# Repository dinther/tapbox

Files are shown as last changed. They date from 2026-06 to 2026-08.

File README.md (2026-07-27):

# tapbox

TapBox turns any music source into a steady Ableton Link tempo and downbeat master—whether the beat comes from a CDJ, an audio signal, or your own finger.

The device is based on a ESP32 controller that joins an [Ableton Link](https://www.ableton.com/en/link/) session over Ethernet or WiFi. Built on the [WT32-ETH01](http://www.wireless-tag.com/portfolio/wt32-eth01/) module with a MAX7219 8-digit 7-segment display. The famous silent sanwa button OBSF 30 serves as your tap button.



## Features

- **Four sources** — **Tap** (manual tap tempo), **Mic** (microphone auto-detects BPM, you tap the downbeat), **Line** (same detection from a 3.5 mm line-level input), and **CDJ** (Pioneer Pro DJ Link). Chosen with the Src menu item; the active source is shown by a bar on the display (top = CDJ, middle = Tap, bottom = Mic, top + bottom = Line)
- **Tap tempo** — tap 4 times to lock in BPM and phase-align to the Link session (Tap source)
- **Audio beat detection** — an INMP441 I2S microphone listens to the room and refines the tempo automatically via an FFT/mel-filterbank onset detector and a dynamic-programming beat tracker (`BTrack`), within a tunable BPM range of your tap — your tap is always ground truth; the detector can never wander off on its own. → [How beat detection works](BEAT_DETECTION.md)
- **Line-in beat detection** — a PCM1808 24-bit stereo ADC feeds a 3.5 mm line-level signal (mixer booth/aux out, media player, phone) into the same detector — no room noise, no mic-to-speaker acoustic delay
- **Pioneer CDJ sync** — passively listens for Pro DJ Link beat packets on the same network; bridges CDJ tempo directly into the Ableton Link session
- **Ableton Link** — joins the Link network automatically on boot; peers shown on display
- **Two-button control** — tap button for tempo and menu navigation; select button for confirm/back
- **Ethernet or WiFi** — Connects to your network as a client; browser config page for credentials; auto-failover to WiFi if no Ethernet present. Can also run as a **WiFi access point** or with a **direct Ethernet cable** to a laptop — no router needed.
- **Static or DHCP** — configure IP address, subnet, and gateway via the web config page
- **IP ticker on boot** — non-blocking scroll of connection type, IP address, and security PIN at startup (Eth, StA, or AP); the PIN doubles as the WiFi AP password and the web config page login; device is fully operational during the scroll
- **OSC control** — UDP server on port 8000 for remote tap, BPM set, nudge, and downbeat reset
- **Menu system** — on-device configuration with NVS persistence across power cycles
- **OTA updates** — open the menu, hold both buttons 3 s, release and confirm; tapbox checks for a newer version first and shows it for you to accept before it reboots to install — so it never burns a reboot when you're already up to date or can't reach the server
- **Factory reset** — open the menu, hold both buttons 8 s, confirm with select; returns device to store-bought state

<p align="center"><a href="https://beatline.xyz/projects/tapbox/" >Button</a></p>

## Hardware

| Component | Part |
|---|---|
| MCU / Ethernet | WT32-ETH01 (ESP32 + LAN8720A) |
| Display | MAX7219 8-digit 7-segment module |
| Input | Two momentary push buttons (tap + select) |
| Microphone | INMP441 I2S MEMS microphone (for Mic source) |
| Line-in ADC | PCM1808 24-bit I2S stereo ADC breakout + 3.5 mm TRS socket (for Line source) |
| Power / charging | Integrated lithium charge/discharge/boost module (often sold as "TP4056 boost module") — USB-C, 1 A three-stage charging, 5 V boost output, automatic charge/discharge switching, charge/discharge/polarity protection, 35 µA quiescent current |

### Pin Assignments

| GPIO | Function |
|---|---|
| IO35 | Tap button — input-only, needs **external 10 kΩ pull-up to 3.3 V** |
| IO39 | Select button — input-only, needs **external 10 kΩ pull-up to 3.3 V** |
| IO4  | INMP441 SCK (I2S bit clock) |
| IO12 | INMP441 WS (I2S word select) |
| IO36 | INMP441 SD (I2S data in) |
| IO14 | MAX7219 CLK |
| IO2  | MAX7219 DIN |
| IO15 | MAX7219 LOAD/CS |
| IO5  | PCM1808 SCKI — 8 MHz system clock, LEDC-generated (silk `RXD`) |
| IO17 | PCM1808 BCK — I2S bit clock, PCM1808-generated (silk `TXD`) |
| IO32 | PCM1808 LRC — I2S word clock, PCM1808-generated (silk `CFG`) |
| IO33 | PCM1808 OUT — I2S data in (silk `485_EN`) |

INMP441 wiring: **VDD → 3.3 V**, **GND → GND**, **L/R → GND** (selects the left channel), plus SCK/WS/SD as above.

PCM1808 wiring: **+5 V and 3.3 V** supplies (this breakout has no onboard regulator), **MD0 → 3.3 V**, **MD1 → 3.3 V** (Master mode, 256fs → 31.25 kHz sampling), **FMT → GND** (I²S format; silk-labelled `PMT` on some boards), **SCK ← IO5**, plus BCK/LRC/OUT as above. The PCM1808 masters the I2S bus; the ESP32 receives as a slave. 3.5 mm socket: **tip → LIN**, **ring → RIN**, **sleeve → the analog GND pin between LIN and RIN**.

> GPIO 0, 16, 18, 19, 21, 22, 23, 25, 26, 27 are used by the onboard Ethernet — do not reassign.  
> GPIO 34–39 are input-only with **no internal pull-up** — the tap/select buttons on IO35/IO39 therefore require external pull-ups.  
> IO12 is a flash-voltage strapping pin (used here for I2S WS); acceptable on the WT32-ETH01.

## Display Layout

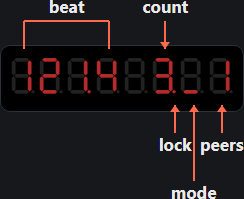
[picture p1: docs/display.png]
Display layout


- **beat** — current BPM, four digits with decimal point (`120.0`)
- **source bar** — horizontal segments: **top = CDJ**, **middle = Tap**, **bottom = Mic**, **top + bottom = Line**
- **count** — beat position in the bar (1–4, or up to your time signature)
- **lock dot** — decimal point on the count digit: **solid** = locked (CDJ active / audio stable / tap set); **blinking** = Mic or Line source searching; **off** = no lock
- **peers** — number of other Ableton Link peers on the network

**Menu mode:**
```
[ label 0 ][ label 1 ][ label 2 ][ label 3 ][ blank ][ value right-justified ]
```
Menu mode example: Beat label with value 4

Value flashes at 4 Hz in edit mode.

## Controls

| Action | Result |
|---|---|
| Tap button (normal mode) | Tap tempo |
| Tap button (menu nav) | Advance to next item |
| Tap button held (menu edit) | Auto-increment value (5/sec after 500 ms, 20/sec after 1500 ms) |
| Select button short press | Enter menu / confirm |
| Select button long press (1 s) | Back / exit menu |

## Menu

| Label | Setting | Values |
|---|---|---|
| Beat | Time signature | 2, 3, 4, 5, 6, 7 |
| Led | Display brightness | 1 – 4 (live preview) |
| Src | Source | Cdj · Aud (mic) · `LinE` (line-in) · tAP (tap) |
| Lan. | Network mode | Auto (DHCP) · Stat (static) · AP (WiFi access point) |
| Addr | Current IP address | read-only; shows last octet; press **select** to scroll full IP across display |
| vEr | Firmware version | read-only; shows major.minor.patch |
| done | Exit menu | returns to normal mode |

Src selects the source. The tuning parameters for the audio beat detector (shared by the Mic and Line sources), plus the static IP address, subnet mask, and gateway, are **web-only** (Network and BPM tuning tabs on the web config page, not on-device menu items) — see [BEAT_DETECTION.md](BEAT_DETECTION.md).  
Changing the network mode reboots after a 2-second `bOOt` display.  
Addr is read-only. Navigating to it shows the last octet of the current IP as a quick reference; pressing **select** scrolls the full IP address across the display.  
Menu times out after 6 seconds of inactivity without saving. The menu resumes at the last-visited item when re-opened.

> Factory reset and OTA update are **not** in the menu — see [System Functions](#system-functions) below.

## System Functions

Both system functions are triggered from **within the menu** by holding both buttons simultaneously. Open the menu first (select short press), then hold both buttons.

### OTA Firmware Update

Open the menu, then hold both buttons for **3 seconds**. The display shows UPd.----. Release — the display shows UPd Yes. Press **select** to check for an update. tapbox contacts the server and compares versions — **no reboot yet**:

- **Already up to date** → shows `UPd no` and returns to the menu.
- **Can't reach the server** (no internet route) → shows `UPd Er` and returns to the menu.
- **A newer version is available** → shows `UP` followed by that version number (e.g. `UP 1.15.0`) and waits for your decision. Press **select** to install it, or **tap** (or wait) to cancel.

Only when you accept the shown version does tapbox save the update flag, erase OTA data if needed, and reboot. On the next boot, as soon as it gets a network connection, it downloads and installs that firmware — the display shows `UPd.` with a progress percentage, then done before rebooting into it.

### Factory Reset

Open the menu, then hold both buttons for **8 seconds**. The display shows UPd.---- at 3 s then rSet Yes at 8 s. Release and press **select** to confirm. tapbox resets all settings and reboots. Press **tap**, hold **select**, or wait 6 seconds to cancel.

## WiFi

tapbox prefers Ethernet. WiFi is used automatically when no Ethernet cable is present, and as a fallback if the cable is unplugged while running.

**First-time setup:**

1. Boot tapbox without an Ethernet cable.
2. Connect your phone or laptop to the **tapbox** WiFi network.
3. Use the 8 digit password shown on the device on bootup. (It is the number shown after the IP address)
4. Open **http://192.168.4.1** in a browser.
5. Enter your regular WiFi SSID and password and tap **Save Network — tapbox will reboot**.
6. tapbox reboots and connects to your network as a client.
7. You know it worked when you see "sta" followed by an IP address on bootup.

The ESP32 radio supports **2.4 GHz only**. If your router broadcasts separate 2.4 GHz and 5 GHz SSIDs, use the 2.4 GHz one.

If WiFi credentials are stored but the connection fails, tapbox falls back to AP mode automatically so you can reconfigure without a factory reset.

## Direct Connection — No Network Required

tapbox can sync with a PC running Ableton Live (or any Link-enabled app) — or directly with a Link-enabled standalone player — without a router or existing network. Three approaches work: tapbox's own WiFi access point, a direct Ethernet cable with automatic addressing, or a direct cable with static IPs on both devices.

### WiFi AP mode

The simplest option — tapbox creates its own WiFi network and everything runs on it.

1. In the menu, navigate to Lan. and set it to AP. Confirm with select — tapbox reboots.
2. On your laptop, connect to the **tapbox** WiFi network and enter the 8 digit password shown on the device at bootup.
3. Ableton Link is active immediately. Tap to set tempo and phase.
4. In AP mode, the web config page is at **http://192.168.4.1** for display and network settings.
5. OSC commands reach tapbox at **192.168.4.1 port 8000**.

> OTA firmware updates are not available in AP mode as there is no internet path. CDJ sync is also unavailable — Pioneer players use a wired network and do not join a WiFi access point.

### Direct Ethernet — automatic

A single patch cable between tapbox and a computer (or a Link-enabled player such as a Denon SC6000) needs **no configuration at all**. Leave tapbox on its default Lan. = `Auto` setting and connect the cable:

1. tapbox looks for a DHCP server for a few seconds; with none on the wire it self-assigns a **link-local address** (`169.254.x.x`) and scrolls it on the display. The address looks random but is derived from the device's MAC, so it stays the same every time.
2. The other end does the same — Windows ("APIPA"), macOS, Linux, and Engine OS players all self-assign in the same `169.254.0.0/16` range when DHCP is absent. On Windows the adapter shows **"Unidentified network — No internet"**; that's normal for a bare cable.
3. Both ends now share a subnet: Ableton Link discovers the peer, the web config page answers at the address on the display, and OSC works on port 8000.

Give the computer up to a minute to give up on DHCP and self-assign — `ipconfig` showing an *Autoconfiguration IPv4 Address* means it's ready.

> **One self-assigned adapter at a time.** Link-local addresses don't identify *which* cable they live on, so if a computer has **several** network adapters in the self-assigned state at once (e.g. two direct cables to different devices), the OS can route the range out of only one of them and the others become unreachable. One direct cable per machine works flawlessly; for anything more elaborate — or any show rig where addresses must never change — use the static IP plan below.

> OTA firmware updates are not available on a direct cable (no internet path).

### Direct Ethernet — static IPs

The managed alternative: both ends set to a fixed address. Addresses never change between sessions, which suits saved OSC configurations and multi-device rigs.

Modern hardware (including the WT32-ETH01 and USB-to-Ethernet adapters) supports auto-MDIX, so a standard patch cable works — no crossover cable is required.

**tapbox — set a static IP:**

1. In the menu, set Lan. to Stat.
2. On the web config page's Network tab, set the static IP, subnet, and gateway. Use a private range that is not in use on any other interface — for example:

   | Setting | Example |
   |---------|---------|
   | `IP  ` | `192.168.10.1` |
   | `Sub.` | `255.255.255.0` |
   | `Hub.` | `192.168.10.1` |

3. Connect the cable. tapbox boots straight to its static address with no DHCP wait.

**Laptop — set the Ethernet adapter to a static IP on the same subnet:**

| Setting | Example |
|---|---|
| IP address | `192.168.10.2` |
| Subnet mask | `255.255.255.0` |
| Default gateway | `192.168.10.1` *(or blank)* |

The web config page is at your chosen **http://192.168.10.1**. Ableton Link and OSC work on the same address. The laptop's WiFi can remain connected to the internet independently.

> Do not set the laptop gateway to an address outside the tapbox subnet — it will cause routing errors on that interface. Leaving the gateway blank or pointing it at the tapbox IP is safe.

### Windows Firewall — letting Link through

Ableton Link needs to *receive* UDP packets, and the Windows Firewall blocks unknown inbound traffic. The telltale symptom: you can ping tapbox and open its web page, but your tapbox display shows **0 peers** — or sees tapbox while tapbox's peers count stays at 0.

Two things make this common:

- Windows classifies a direct cable as an **"Unidentified network"** and applies the strict **Public** firewall profile, even if the app was already allowed on Private networks.
- If the "allow access" prompt on an app's first run was ever cancelled, Windows silently created a **Block** rule that keeps winning on every network.

**To allow your Link app (Ableton Live, MadMapper, …):**

1. Press **Start**, type "firewall", open **Allow an app through Windows Firewall**.
2. Click **Change settings** (needs administrator rights).
3. Find your app in the list. Tick the checkbox on the **left of its name**, then tick both the **Private** and **Public** columns.
4. Click **OK** and restart the app.

Or as a single command in an **administrator** PowerShell (replace the name with the app's entry as it appears in the firewall list):

```powershell
Set-NetFirewallRule -DisplayName "Ableton Live 12 Trial" -Action Allow -Profile Private, Public
```

If the app is not in the list yet, launch it once, enable Link, and accept the firewall prompt — ticking **both** network types.

## Web Configuration

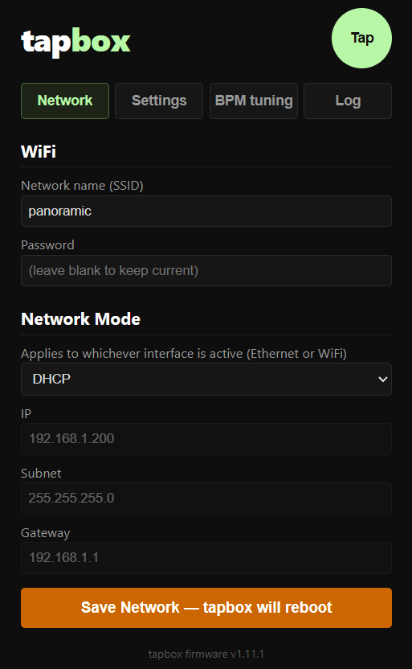
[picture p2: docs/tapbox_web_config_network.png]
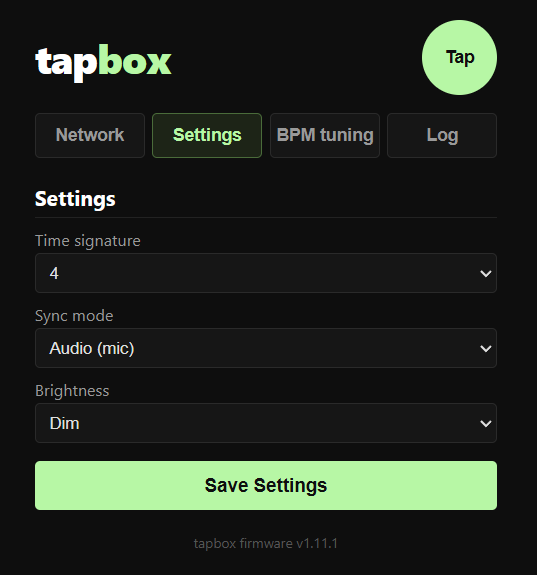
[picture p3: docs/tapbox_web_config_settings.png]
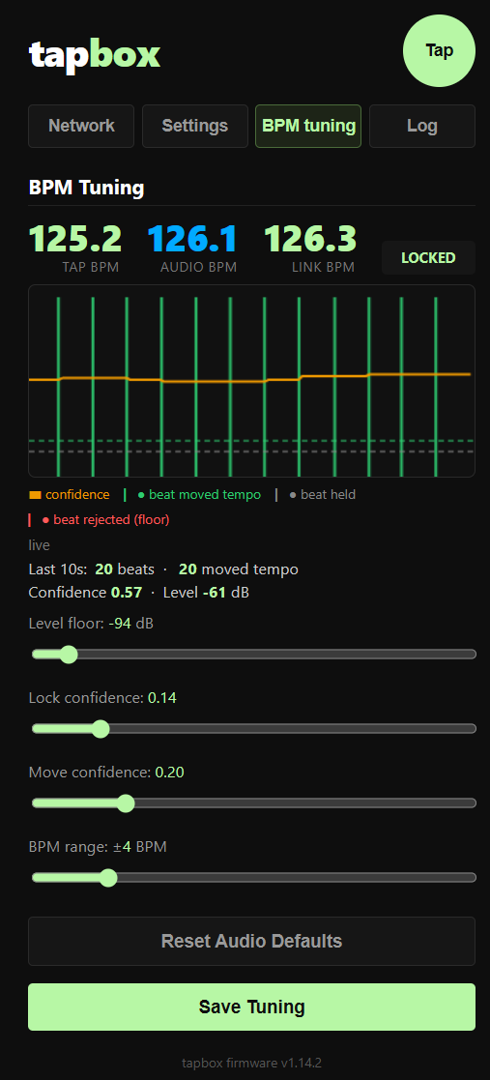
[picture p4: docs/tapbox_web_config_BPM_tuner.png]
  

The config page at `http://<tapbox-ip>` is accessible from any browser over Ethernet or WiFi. A **Tap** button above the tabs works from any of them — same tap the physical button drives. It has four tabs:

| Tab | Fields | Button | Effect |
|-----|---|---|---|
| Network | WiFi SSID/password, Ethernet mode, static IP/subnet/gateway | Save Network — tapbox will reboot | Saves and reboots |
| Settings | Time signature, source, brightness | Save Settings | Saves and applies live — no reboot |
| BPM tuning | Level floor, lock confidence, move confidence, BPM range, plus a live confidence chart | Save Tuning | Applies live as you drag; see [BEAT_DETECTION.md](BEAT_DETECTION.md) |
| Log | Live scrolling log of tap/arm/lock events over the same WebSocket the chart uses — no controls, view-only | — | — |

## OSC Interface

Send UDP packets to the device on **port 8000**.

| Address | Argument | Action |  
|---|---|---|
| `/tap` | — | Same as the tap button |
| `/bpm` | `float` or `int` | Set BPM directly |
| `/signature` | `int` | Set time signature (2–7) |
| `/nudge` | `int` (ms, signed, optional) | Nudge phase by `ms` (+ = advance, − = retard); no argument = 20 ms |
| `/downbeat` | — | Reset downbeat to now |

## Installing

Flash tapbox to your WT32-ETH01 directly from your browser — no software installation required:

**[Open Web Installer](https://dinther.github.io/tapbox/)**

Requires Chrome or Edge. Windows users may need the [CH340 driver](https://www.wch-ic.com/downloads/CH341SER_EXE.html) if the board is not detected.

Pre-built binaries are also available on the [Releases](https://github.com/dinther/tapbox/releases) page for manual flashing with esptool.

## Tools

Two Python scripts in `tools/` assist with development and testing. Both require Python 3 and no external packages.

### CDJ Simulator (`tools/cdj_sim_web.py`)

Broadcasts genuine Pro DJ Link 0x28 beat packets on UDP port 50001 — useful for testing CDJ sync without real hardware.

```bash
python tools/cdj_sim_web.py [bpm] [player]
```
{47560FA2-C87A-4E2B-8EA1-346BB672038C}

Opens a browser-based control page at **http://localhost:8080** with:
- Live BPM display with ±1 / ±0.1 nudge buttons and a slider
- Beat-in-bar indicator (4 circles, beat 1 highlighted in amber)
- Player selector (1–4)
- Stop / Start toggle (tests the 2-second CDJ timeout on tapbox)
- **Downbeat** button — sends `Bb=1` immediately, triggering a bar-phase snap on tapbox

### Link Monitor (`tools/link_monitor.py`)

Prints the current Ableton Link session tempo and peer count to the terminal, useful for verifying that tapbox is pushing the right BPM into the Link session.

```bash
python tools/link_monitor.py
```

## Building

Requires [PlatformIO](https://platformio.org/).

```bash
# Build
python -m platformio run

# Build and flash
python -m platformio run --target upload
```

## License

MIT

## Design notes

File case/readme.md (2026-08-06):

## CAD Files
The case was created with OpenSCAD. This is the included tapbox_case.scad file. This is a open source parametric script driven cad program which is perfect for the creation of 3D printable parts. You can find OpenSCAD here: https://openscad.org/

The bottom four lines of the source can be uncommented for the part you want to generate.

## STL Files
You can also just use the STL files included in this folder. These are optimized for the specific parts I have on hand but they may suit you too.

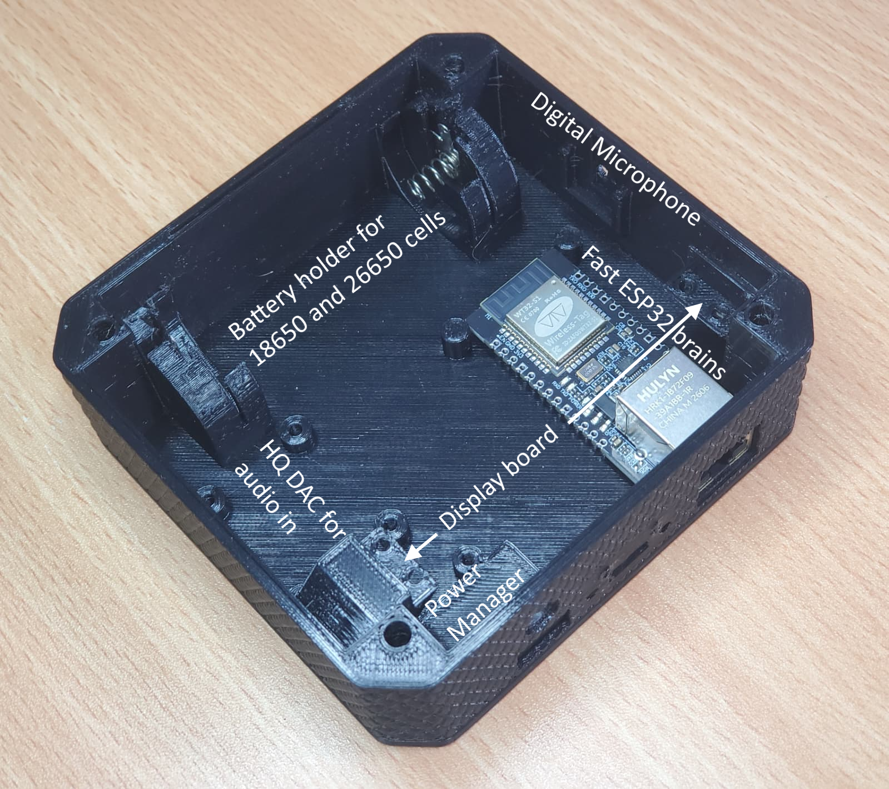
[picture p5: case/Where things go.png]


## Texturizing
I textured part of the case in order to hide layer lines that are otherwise unavoidable with FDM printing. For this I used https://bumpmesh.com an excellent browser based stl texturizer. I uploaded texture.png for the texture in this program.

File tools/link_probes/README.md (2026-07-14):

# Ableton Link probe scripts

Packet-level diagnostics for Link discovery/session problems, written while
debugging why Link peers fail to sync over a direct Ethernet cable with
link-local (169.254.x.x) addressing. Python 3 standard library only.

All scripts have the local interface addresses and the peer's address
**hardcoded near the top** (`ETH_IP`, `WIFI_IP`, `TAPBOX`) — adjust them to
your setup before running (`ipconfig` shows yours; the tapbox display scrolls
its own).

| Script | What it shows |
|---|---|
| `link_sniff_nodes.py` | Which Link peers (by node id) are transmitting on which interface. Confirms TX and interface binding without trusting any app's UI. |
| `link_pkt_compare.py` | Full decode of one ALIVE per peer: protocol version, group id, node id, tempo, session id, measurement endpoint. Spots structural incompatibilities. |
| `link_mcast_probe.py` | Replays a captured ALIVE to a device via unicast and via multicast and watches for a RESPONSE — separates message-processing failures from multicast-delivery failures. |
| `link_fake_peer.py` | Impersonates a complete Link peer (fresh node/session id, measurement endpoint pointed at its own socket) and reports whether the device under test answers discovery and initiates measurement pings. The full merge handshake, observable end to end. |
| `laseros_pong_test.py` | The decisive subnet-filter test: captures a genuine measurement ping, replays the identical bytes from a *same-/24* source, and watches for a pong. A responder that pongs the replay but ignored the original is filtering by source subnet. |

## Background

Ableton Link builds from Feb 2024 (upstream commit `a273b36`) to Mar 2026
(removed in `d466f42`) contain a hardcoded /24 source-subnet filter in
discovery. Link-local addressing is a /16, so two directly-cabled devices
usually land in different /24s and a filter-era peer goes silently deaf to
the other end. tapbox firmware ≥ v1.14.2 carries the upstream removal; these
scripts identify the same defect in other Link applications.

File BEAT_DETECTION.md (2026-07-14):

# tapbox — Audio Beat Detection

How the audio BPM detection works, end to end.

This describes the two **audio sources** — **Mic** (`MODE_MIC`, INMP441
microphone) and **Line** (`MODE_LINE`, PCM1808 line-in ADC) — out of the four
sources (CDJ / Mic / Line / Tap). The two differ only in capture hardware and
sample rate (§3); from the FFT onward (§4–13) the pipeline is identical, so
where the prose below says "the mic," read "whichever audio source is active."
All of the logic lives in `mic_task()` and `do_tap()` in `src/main.cpp`, plus
the DSP core ported (MIT-licensed) from
[absent42/esphome-audio-reactive](https://github.com/absent42/esphome-audio-reactive)
into `src/dsp/`.

> Diagrams use [Mermaid](https://mermaid.js.org/) (GitHub renders them inline)
> plus ASCII where a waveform is clearer than a flowchart.

---

## 1. Design philosophy

The hard problem in automatic beat tracking is the **downbeat** — knowing which
pulse is "beat 1". tapbox sidesteps it by splitting the job between the human and
the machine:

| Job | Owner | Why |
|-----|---|-----|
| **Tempo** (BPM) | the **audio source** (mic or line-in) | machines are good at measuring intervals |
| **Downbeat** (phase / "beat 1") | the **tap button** | humans hear musical phrasing |

So: **you tap the downbeat, the detector carries the tempo.** Your tap is *ground
truth*; the detector is only ever allowed to refine and track *around* it. This single
rule is why the system stays trustworthy — the detector can never wander off on its own.

```mermaid
flowchart LR
    A[Music in the room] -->|acoustic| MIC[INMP441 mic]
    B[Mixer / player output] -->|3.5mm line| ADC[PCM1808 ADC]
    MIC -->|tempo| LINK[Ableton Link grid]
    ADC -->|tempo| LINK
    TAP[Your tap] -->|downbeat / anchor| LINK
    LINK --> OUT[Synced devices]
```

---

## 2. The detection pipeline

A proper FFT-based pipeline, ported from a MIT-licensed ESP32 audio-analysis
library and re-derived for tapbox's rates — 32kHz mic / 31.25kHz line-in (the
library targets ESPHome devices at 22.05/44.1kHz):

1. **`FFTProcessor`** — real FFT via [kissfft](https://github.com/mborgerding/kissfft) (vendored, BSD-3-Clause)
2. **`MelFilterbank`** — 32-band log-mel spectral representation
3. **`SuperFluxOnset`** — log-mel, max-filtered spectral flux (Böck & Widmer,
   DAFx 2013) — tuned to reject vibrato/legato and pick genuine attacks across
   the whole spectrum, not just one band
4. **`BTrack`** + **`TempoEstimator`** — a cumulative-score dynamic-programming
   beat tracker with fractional-lag harmonic-template tempo induction and a
   leaky-integrator smoother, re-implemented against the
   [adamstark/BTrack](https://github.com/adamstark/BTrack) reference

---

## 3. Capturing audio (I2S)

Two independent capture paths; `mic_task()` is the single reader and consumes
whichever one the Source setting selects, resetting the whole pipeline
(filterbank geometry, SuperFlux, BTrack, arm/lock state) on a switch — so
re-tap once after switching sources.

**Mic** (`MODE_MIC`, I2S0, ESP32 as master):

- **INMP441** digital I2S MEMS mic, `L/R` tied to GND.
- Sample rate: **32 kHz**.
- INMP441 channel selection on the ESP32 is a known finicky point (L/R→GND
  *should* select the left slot, but configs don't always behave). In our
  bring-up, **mono mode returned all-zero samples on both slot settings**, while
  reading **both** slots in stereo and using only the **left** samples worked
  reliably — so that's what we do (`i += 2` through the buffer). This is an
  empirical workaround for our setup, not a documented driver bug.

**Line** (`MODE_LINE`, I2S1, ESP32 as slave):

- **PCM1808** 24-bit stereo ADC fed from the 3.5 mm line input; both channels
  are averaged to mono into the same ring buffer.
- The **PCM1808 masters the I2S bus** (MD0/MD1 strapped high = Master mode,
  256fs): it derives BCK (2 MHz) and LRCK internally from an **8 MHz system
  clock** the ESP32 generates with LEDC (80 MHz APB ÷ 10, an exact integer
  division — a fractional divider would jitter, and SCKI jitter degrades the
  ADC). Single clock domain by construction; the ESP32 just listens as an
  I2S slave receiver.
- Sample rate: 8 MHz ÷ 256 = **31.25 kHz** — deliberately close to the mic's
  32 kHz so the pipeline keeps its character across sources.
- See `PCM1808_PLAN.md` for the full bring-up (wiring, straps, scope
  checkpoints).

---

## 4. FFT + spectral analysis

Raw samples accumulate into a ring buffer; once **1024 samples** (a 32ms window)
are available, a real FFT runs and the window slides forward by a **512-sample
hop** (16ms) — 50% overlap, giving a **62.5Hz** frame rate for everything
downstream (`kFrameHz` throughout `src/dsp/`).

On **line-in** the same 512-sample hop at 31.25 kHz gives **61.035 Hz** — but
`kFrameHz` is a compile-time constant inside `btrack.h`/`tempo_estimator.h`,
so the estimator's reported BPM would read 2.4% high on line-in. `mic_task()`
corrects this at the point of consumption: line-in BPM readings are scaled by
61.035/62.5 (×0.97656) before the octave fold, gates, and Link ever see them.
Confidence is unitless and needs no scaling.

```mermaid
flowchart LR
    I2S["I2S read: ~128 samples/read"] --> RING["RingBuffer&lt;float,2048&gt;"]
    RING -->|"1024 samples available"| FFT["FFTProcessor&lt;1024&gt;<br/>(kissfft, Hamming window)"]
    FFT -->|"magnitudes²"| MEL["MelFilterbank&lt;32,1024&gt;<br/>80Hz–16kHz, log-mel"]
```

512 usable FFT bins (`1024/2`) at 32kHz give 31.25Hz/bin resolution — coarser
than the upstream library's own 2048-pt/44.1kHz config (21.5Hz/bin), but half the
per-FFT compute cost, which matters since this all runs inline in `mic_task`
alongside I2S reads, sharing the chip with WiFi/Ethernet/HTTP/Link (no core
pinning is used anywhere in this codebase).

**This is the fast path** — the FFT→Mel→SuperFlux→BTrack chain (§3–6) runs on
*every hop* (62.5Hz). `BTrack::process()` is a stateful per-frame machine with
internal countdown timers; it must be fed every hop to behave correctly.

---

## 5. Mel filterbank + SuperFlux onset detection

The squared FFT magnitudes feed a 32-band triangular mel filterbank (80Hz–16kHz
on the mic; the top band drops to 15kHz on line-in, under its 15.625kHz Nyquist)
— the same perceptually-scaled representation used in most music-information-
retrieval onset detectors, giving finer resolution at low frequencies (where
kicks and bass live) than a linear FFT bin split would.

`SuperFluxOnset` (Böck & Widmer, DAFx 2013) then computes onset **strength** per
frame:

1. Log-compress the current mel frame
2. **Max-filter** the previous frame across ±3 neighboring mel bins — this
   specifically suppresses vibrato/legato content, which would otherwise look
   like a continuous stream of small "onsets" to a naive frame-difference
   detector
3. Half-wave-rectified difference between the current (log) frame and the
   max-filtered previous one = flux
4. Adaptive peak-picking (local-max window ± 3 frames, must exceed the local
   mean by a delta threshold over a ±10/+3 frame window) with a minimum
   36–48ms between onsets

The result is a continuous **onset-strength** signal plus a boolean **event**
flag on frames where a genuine onset is confirmed — this strength signal is what
feeds tempo tracking (§6), every hop, regardless of whether `event` fired.

---

## 6. BTrack — tempo tracking

`BTrack` consumes the onset-strength signal every hop and maintains:

- An **onset-history ring** (`kHistoryLen` = 384 frames ≈ 6.1s at 62.5Hz)
- A **cumulative-score** dynamic-programming array, blending the current onset
  strength with the best-scoring past state within a `[beat_period/2,
  2×beat_period]` window (log-Gaussian weighted) — this is what lets it predict
  *when* the next beat should fall, not just detect that a beat happened
- A **beat-prediction** step that extrapolates the cumulative score forward and
  picks the most likely next beat frame

**Tempo induction** (working out the actual BPM, as opposed to predicting the
next beat *given* a known BPM) runs once per predicted beat and is delegated to
`TempoEstimator`:

- Scores a continuous **60–180 BPM grid** (121 candidates, 1-BPM steps) using a
  **fractional-lag harmonic template** (4 harmonics of the candidate's beat
  period, evaluated at exact fractional lags into the autocorrelation, avoiding
  the bias integer-lag binning would introduce)
- A gentle **log-normal prior** centered on 120 BPM nudges octave ambiguity
  without creating a hard attractor
- A **leaky integrator** smooths estimates across updates — old evidence decays
  geometrically, so a wrong lock is escapable within roughly 10 beats
- **Confidence** is the fraction of the smoothed state's mass sitting within
  ±2 BPM of the current best estimate — high on real rhythmic music, near-zero
  on noise or silence — gated by requiring 4 consecutive updates to agree within
  ±3 BPM before calling the estimate "locked"

`BTrack` publishes `{bpm, beat_phase, confidence, beat_event}` every hop.
Confidence is forced to 0 for the first ~3 seconds after reset (`kWarmupFrames`)
while the onset-history ring fills with real data.

**Known limitation** (documented in `tempo_estimator.h`, inherited from the
upstream library's own measurements): the reliable range is **~85–160 BPM**.
Outside it, octave/sub-harmonic aliasing dominates — material with strong
eighth-note content below ~85 BPM confidently reports double tempo; above ~164
BPM a 2:3 or 1:2 alias can win. This isn't a tapbox-specific bug; it's an
inherent property of autocorrelation-based tempo induction on eighth-note-heavy
material, present in the reference implementation this was built against.

---

## 7. Arming — the tap is ground truth

With a Mic or Line source, the detector is **display-only until you tap.** Your tap sets two
references used by everything downstream:

- `g_mic_tapAnchor` — the **anchor** tempo (centre of the octave fold and the BPM range gate, §8)
- `g_mic_tracked` — the **applied** tempo (what goes to Link)

All three — Tap, Audio, Link — are shown live as big numbers at the top of
the BPM tuning tab, so you can see your own tap alongside what the mic is
hearing and what's actually being published.

**Tap grammar** (the box infers intent from how many taps arrive < 2 s apart):

```mermaid
flowchart TD
    T[Tap] --> N{How many taps<br/>in this session?}
    N -->|1 tap, then stop| ONE[Accept current mic BPM<br/>+ set downbeat = now]
    N -->|4+ taps| FOUR[Override tempo to tapped BPM<br/>+ re-anchor the mic]
    ONE --> ARMED[Armed - mic now tracks around anchor]
    FOUR --> ARMED
```

- **One tap** = "I agree, beat 1 is *now*" — accepts the mic's current estimate
  and sets the downbeat.
- **Four taps** = override the tempo with your own tapping, re-anchoring the mic.
- Once armed and locked, a **lone tap just re-syncs the downbeat** without
  touching the tempo (the mic owns BPM).

---

## 8. Follow/hold — applying BTrack's tempo

A beat only reaches the tiers below if it clears an **absolute level floor**
first (`g_micFloor`, dB, BPM tuning tab slider, default off at -100dB).
`SuperFlux` measures *relative* spectral change, so a quiet room still
produces confident, periodic "beats" out of something as unmusical as
keyboard typing — there is no loudness floor anywhere upstream of this gate.
A beat whose level falls below `g_micFloor` counts for **nothing**: not lock,
not PLL, not tempo. (Discovered when typing near an armed, silent tapbox
produced a run of confident, evenly-spaced "beats.")

The level checked is **smoothed, not the raw per-hop reading**: a single
32ms FFT hop's power swings roughly 20dB on room noise alone (measured
2026-07-09 — mic self-noise/room hum, not transient events), which is too
noisy to gate on directly. `frameLevelDb` (raw) feeds `levelEmaDb`, an
~800ms EMA (0.98/0.02 blend at the 62.5Hz hop rate); the floor gate and the
web page's Level readout both read `levelEmaDb`, not the raw value.

Confidence is **two-tier**, both tiers tunable sliders (`g_micConfSil` /
`g_micConfMove` on the BPM tuning tab, defaults 0.30 / 0.60) because usable
confidence varies a lot with the mic and the room — there's no fixed value
that works everywhere. Above the **lock** tier a beat keeps the lock alive
and the PLL phase-nudging (§9): beat *timing* stays useful even when the
tempo estimate is smeared. But **moving** the tempo requires the **move**
tier — most of `BTrack`'s probability mass agreeing on one value. This
matters because a quiet, beat-free passage can keep confidence just above a
low, fixed floor while the estimate wanders onto a harmonic alias — requiring
higher confidence to move turns that passage into a HOLD instead of an
alias-driven jump.

**FOLLOW** — on each beat clearing the level floor and the move tier, the
tempo is driven directly:

**(a) Octave fold toward the tap anchor** — the one disambiguation `BTrack`
demonstrably still needs (§6's ~85–160 BPM aliasing limit). The *operator*
knows which octave they meant; the fold applies that knowledge:

```c
while (cand > anchor * 1.4) cand *= 0.5;
while (cand < anchor * 0.7) cand *= 2.0;
```

The fold anchors to the **fixed tap anchor**, not the wandering output —
anchoring to the output would let a drift feed back on itself.

**(b) Snap, with an anti-flicker deadband** — if the folded candidate differs
from the tracked tempo by more than 0.4 BPM, the tracked tempo is set **equal
to it** in one step. No crawl: Link converges as fast as `BTrack` does. Moves
of 0.4 BPM or less are ignored, so the tempo published to every Link peer
doesn't flicker with estimation jitter — and because every real move lands
exactly *on* the candidate (rather than a slew stopping short of it), there is
no standing measured-vs-Link offset for the phase-lock (§9) to absorb.

**(c) BPM range gate** — a candidate more than `g_micRange` BPM from the tap
anchor (`g_mic_tapAnchor`, default ±6, tunable 1–20 on the BPM tuning tab)
does not move the tempo, full stop, no matter how confident the beat is.
Unlike (a)/(b), this isn't a fixed constant — it's the main knob for how much
you trust audio sensing to refine around your tap versus treating the tap as
the whole story (2026-07-09 redesign: the anchor itself never moves except by
re-tap; this gate only bounds how far `g_mic_tracked` may wander from it).
Binary in/out for now, no graduated confidence-vs-distance requirement yet.
Because `g_mic_tracked` can only ever be *set* to a candidate that already
passed this check, it's bounded to anchor±range by construction — there's no
separate clamp step the way the old fixed ±20% rail needed.

**HOLD** — anything below the move tier (silence, a breakdown, a beat-free
passage, a confidence dip mid-transition), below the level floor (typing,
handling noise), or **outside the BPM range gate** (a candidate too far from
the anchor to trust) freezes the tempo at its last good value. Nothing
chases low-confidence, too-quiet, or out-of-range readings; beats clearing
the floor and the lock tier (but not move-tier confidence, or not in range)
still maintain the lock and phase alignment, and `tapbox`'s lock drops after
the timeout (§9) if even those stop — but the tempo number stays put until a
beat clears every tier at once.

Beat events are latched across the fast 62.5Hz hop loop (`btBeatSincePoll` in
`mic_task()`) — each latch also stamps the beat hop's own smoothed level and
timestamp (`beatLevelDb`/`beatMs`, see the level-floor note above), so the
gate judges the beat's actual energy rather than whatever the slower 20Hz
poll sees — and consumed by that poll, so no `beat_event` is ever missed
between polls.

---

## 9. Applying to Link — tempo *and* phase-lock

```c
abl_link_set_tempo(session, tracked, t);          // always: tempo
if (locked) {                                      // only once locked:
    beat    = abl_link_beat_at_time(session, t);
    nearest = round(beat);
    fixed   = beat + 0.15 * (nearest - beat);      // low-gain phase nudge
    abl_link_force_beat_at_time(session, fixed, t);
}
```

Once **locked** (4 consecutive confident beats), a low-gain **phase-locked loop**
gently pulls the beat grid so each detected beat sits on the **nearest** beat —
never a whole bar, so the bar position you tapped is preserved.

---

## 10. Lock state & lifecycle

```mermaid
stateDiagram-v2
    [*] --> DisplayOnly: enter Mic or Line source
    DisplayOnly --> Armed: tap (sets anchor + downbeat)
    Armed --> Locked: 4 consecutive confident beats
    Locked --> Armed: no confident beat for 6 beat-periods (min 3.5s)
    Armed --> DisplayOnly: leave Mic/Line source
    Locked --> DisplayOnly: leave Mic/Line source
    Locked --> Locked: re-tap = re-sync downbeat
```

There are two layers of gating, worth keeping distinct:

- **`BTrack`'s own confidence/lock** (§6) — internal to the DSP, decides whether
  its BPM candidate is trustworthy at all. Can flicker during an active tempo
  change (e.g. a DJ pitch-bending a track) — that's expected, not a bug.
- **tapbox's armed/locked state** (this section) — fed by *confident* beats
  (§8's FOLLOW events): requires 4 confident beats in a row, drops after 6
  beat-periods (minimum 3.5s) without one.

A sustained confidence dip in `BTrack` (silence, a breakdown) puts the tempo
in HOLD and, past the timeout, drops tapbox's lock — but `BTrack`'s own `bpm`
field keeps updating underneath regardless of confidence, so it typically
re-locks within a couple of beats once confident beats return.

---

## 11. Tuning chart — BTrack's own signals, live

The web config page's **BPM tuning** tab chart plots exactly the quantities
the follow/hold logic (§8) compares, in their native units, over a rolling
6-second window.

**2026-07-09: the chart was a BPM strip (raw/Link BPM traces, top) stacked
over a confidence strip (bottom) — the BPM strip was removed entirely** (it
plotted a hardcoded ±20% band that no longer matched the real gate once
`g_micRange` replaced the fixed clamp, and the numbers it showed are already
covered live by the Tap/Audio/Link readouts at the top of the tab, §7). What
remains is a single **confidence strip**: the confidence trace (orange)
against the **lock** (grey dashed) and **move** (green dashed) slider
thresholds, redrawn live as the sliders move, plus a vertical tick per
BTrack-predicted beat — bright green if it cleared the move tier and the BPM
range gate (it drove the tempo), dim grey if it only cleared the lock tier
(including a beat confident enough to move tempo but outside the BPM
range), **red if BTrack predicted a beat but the level floor rejected it**.
A run of grey/green ticks poking above the move line with no music playing
is the typing-noise failure mode; a run of RED ticks during real music is
the opposite failure — real beats being wrongly rejected.

The chart, the live **Confidence**/**Level (dB)** readout beneath it (Level
is the same ~800ms-smoothed value the floor gate checks, §8), and the
"Last 10s: N beats · M moved tempo" line are all fed by the same 20Hz
telemetry packet `mic_task()` pushes over the `/ws` WebSocket. The chart
lives in the embedded copy in `http_get_root()` (`mDraw()`).

---

## 12. Live event log (web page "Log" tab)

A fourth tab on the web config page shows a scrolling, timestamped log of
notable events — useful for testing without a serial cable attached (e.g.
watching tempo tracking behavior while changing pitch/speed in DJ software).
Logged over the same `/ws` WebSocket connection the tuning chart uses,
distinguished from the telemetry CSV by an `L` prefix.

**Logged today:**
- Tap events — armed, downbeat re-synced, tap override (from `do_tap()`)
- Lock transitions — "Locked at N BPM" / "Lock lost (was N BPM)" (edge-triggered
  in `mic_task()`)

**Not logged:** a per-beat trace of `BTrack`'s raw (pre-confidence-gate) BPM
estimate — the existing "Audio BPM" readout already shows the
confidence-gated value live at 20Hz.

The log only does work while a browser has the page open (same
`ws_client_connected()` gate the chart telemetry uses), keeps no server-side
buffer, and caps at 300 lines client-side (older lines drop off, nothing
persists across a page reload).

---

## 13. Tuning knobs (web config page only)

None of these are on-device menu items — the on-device menu only carries
settings usable without a browser at hand (see `src/main.cpp`, `enum MenuIdx`).
All four mic-tuning parameters live on the **BPM tuning** tab of the web
config page, and all four are the real tempo path's actual gates (§8), not
chart-only knobs:

| Web field | Variable | Default | What it does |
|---|---|---|---|
| Level floor | `g_micFloor` | -100 dB (off) | Absolute floor, dB, checked against the ~800ms-smoothed level (§8), not the raw per-hop reading. Below it, a beat counts for nothing — no lock, no PLL, no tempo move. Range -100..-10. |
| Lock confidence | `g_micConfSil` | 0.30 | `BTrack` confidence required to keep the lock alive and feed the phase-lock PLL. |
| Move confidence | `g_micConfMove` | 0.60 | `BTrack` confidence required to actually change the tempo (FOLLOW vs. HOLD, §8). |
| BPM range | `g_micRange` | ±6 BPM | How far a candidate may be from the tap anchor and still move the tempo (§8's FOLLOW (c)). Outside it → HOLD, same as failing the confidence floor. Binary in/out, range 1–20. |

They're sliders rather than constants because none of the four has a value
that works everywhere: achievable confidence depends on the mic and the room,
the useful level floor depends on ambient noise and how loud the source is,
and how far you trust audio sensing to refine your tap is a judgment call
only you can make. Tune the floor and confidence tiers against the live
chart (§11) — play music, watch where the confidence trace and level readout
sit, then set them just outside that range.

**Level floor tuning note (2026-07-09):** a raw, unsmoothed single-hop level
reading is too noisy to gate on — measured swinging ~20dB during genuine
silence (mic self-noise/room hum, no transient events) in one real setup,
enough to overlap with quiet-to-moderate music at normal listening volume.
The ~800ms smoothing (§8) fixed this; with it, silence and music separated
into distinct (if sometimes narrow, depending on listening volume) bands. The
**factory default stays -100dB (off)** deliberately rather than shipping a
pre-tuned floor — an aggressive default would silently break audio-mode BPM
tracking for anyone who hasn't tuned it for their room, which is worse than
the false-beat problem a floor prevents. The **Line source largely sidesteps
this**: a line feed is electrically clean (no room noise, no typing, no
audience), so the floor mainly earns its keep on the mic. Note the floor —
like all four knobs — is a single shared value, not per-source; if you tune
it aggressively for a noisy room on the mic, remember it also applies to the
(much quieter) line input.

Fixed constants (not exposed): anti-flicker deadband 0.4 BPM, level-EMA time
constant ~800ms, PLL gain 0.15, lock = 4 confident beats, lock timeout =
6 beat-periods (min 3.5s), `BTrack` warmup ~3s.

---

## 14. Source map

| Piece | Location |
|---|---|
| FFT / mel filterbank / onset / beat tracker (ported DSP core) | `src/dsp/{fft_processor,mel_filterbank,superflux_onset,btrack,tempo_estimator}.h` |
| Vendored kissfft (BSD-3-Clause) | `src/dsp/third_party/kissfft/` |
| Mic I2S init (I2S0 master, stereo, left slot) | `init_i2s_mic()` in `src/main.cpp` |
| Line-in I2S init (I2S1 slave RX) + 8 MHz SCKI clock | `init_i2s_line()` / `line_clock_start()` in `src/main.cpp` |
| Capture (either source) → FFT → Mel → SuperFlux → BTrack → follow/hold → Link | `mic_task()` in `src/main.cpp` |
| Tuning chart (confidence strip, §11) | embedded in `http_get_root()` in `src/main.cpp` |
| Tap grammar (arm / override / re-sync) | `do_tap()` in `src/main.cpp` |
| Source + lock display (source bars, lock dot on beat digit) | `update_display()` in `src/main.cpp` |
| Live event log (web page Log tab) | `ws_log()` in `src/main.cpp` |
| Native (host-buildable) unit tests for the ported DSP core | `test/test_{ring_buffer,fft_processor,onset_detector,mel_filterbank,superflux_onset,btrack,tempo_estimator}/` |

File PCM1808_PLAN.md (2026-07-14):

# PCM1808 Line-In — Wiring & Bring-Up Plan

Staged plan for adding the PCM1808 24-bit stereo line-in ADC alongside the
INMP441 mic. Each phase ends with an oscilloscope (or observable) checkpoint
that must pass before the next wire goes on — so a failure always has a
one-phase search space. Phases 1–4 touch only previously unused pins; the
device stays fully functional throughout. Phase 5 is the only rewiring phase.

Board pinout confirmation: `component_images/WT32-ETH01-pinout.png` (silk
`RXD`=IO5, `TXD`=IO17, `CFG`=IO32, `485_EN`=IO33; IO35/36/39 input-only).
PCM1808 breakout: `component_images/PCM1808.png` (silk `PMT` = datasheet FMT).

## Clocking design (settled — don't revisit without cause)

- PCM1808 runs in **Master mode**: it derives BCK/LRCK internally from SCKI,
  so there is exactly one clock domain. (Slave mode was rejected: ESP32 would
  generate SCKI via LEDC and BCK/LRCK via I2S from two independent dividers
  that drift apart → periodic PCM1808 resync mutes, datasheet §7.3.3.)
- **SCKI = 8.000 MHz** from LEDC: 80 MHz APB ÷ (divider 5 × 2¹) — integer
  divider, zero cycle-to-cycle jitter. 16 MHz is NOT achievable jitter-free
  (needs fractional divider 2.5; LEDC fractional dividers alternate two
  periods and SCKI jitter degrades the ADC, datasheet §10.1.6).
- **256fs** master mode → fs = 8 MHz ÷ 256 = **31.25 kHz** (mic stays 32 kHz;
  hop rate 61.04 Hz vs mic's 62.5 Hz — close enough that the DSP keeps its
  character, but the rate must be a per-source runtime value, not the
  compile-time constant).
- ESP32 receives as **I2S slave RX** on a second port — slave pins route via
  the GPIO matrix, any GPIO works. (The GPIO0/1/3-only restriction applies
  only to the I2S peripheral's dedicated MCLK *output*; irrelevant here.)
- Boot behaviour is inherently safe: until LEDC starts, SCKI is static, which
  the PCM1808 defines as power-down/reset (datasheet §7.4.2).

## Final wiring reference

| Signal | GPIO | Silk | Notes |
|---|---|---|---|
| PCM1808 SCKI | IO5 | `RXD` | LEDC 8 MHz output |
| PCM1808 BCK | IO17 | `TXD` | PCM1808 output → ESP32 input, 2.000 MHz |
| PCM1808 LRC | IO32 | `CFG` | PCM1808 output → ESP32 input, 31.25 kHz |
| PCM1808 OUT | IO33 | `485_EN` | audio data → ESP32 input |
| PCM1808 MD0 | — | | strap **HIGH** (10 kΩ to 3.3 V) |
| PCM1808 MD1 | — | | strap **HIGH** (10 kΩ to 3.3 V) → Master, 256fs |
| PCM1808 FMT (`PMT`) | — | | strap **LOW** (10 kΩ to GND) → I²S 24-bit |
| PCM1808 +5V / 3.3V / GND | — | | both supplies required (5 V analog, 3.3 V digital) |
| Tap + Select buttons | IO35 | | Phase 5: resistor ladder (10 kΩ pullup; tap 10 kΩ, select 22 kΩ to GND) |
| 3.5 mm jack detect | IO39 | | Phase 5: 10 kΩ pullup, jack switch contact to GND |
| INMP441 / display | IO4,12,36 / IO14,2,15 | | unchanged |

## Phase 1 — SCKI clock only (no new wiring)

- [x] Firmware: LEDC 8 MHz output on IO5 (`line_clock_start()` in main.cpp)
- [x] Flash, then scope IO5 at the header.

**Checkpoint: PASSED 2026-07-14** — 8 MHz square wave on IO5, ~3.6 Vpp on the
scope (edge overshoot; logic level is 3.3 V). Flashed as part of v1.12.1.

## Phase 2 — PCM1808 powered, master mode proven (no data pins yet)

- [x] Wire: +5V, 3.3V, GND(s), MD0/MD1/FMT straps, SCKI ← IO5.
- [x] Scope the PCM1808 board's own BCK and LRC pins.

**Checkpoint: PASSED 2026-07-14** — BCK = 2.000 MHz, LRCK = 31.25 kHz, both
generated by the PCM1808 (Master/256fs confirmed). As-built notes: breakout
has NO onboard LDO (both 5 V and 3.3 V wired externally); MD0/MD1 tied
directly to the 3.3 V rail (no strap resistors — datasheet-sanctioned);
FMT is silk-labelled `PMT` on this board. Bring-up hiccup for the record:
with SCKI unconnected the chip sits in clock-halt power-down and BCK/LRC
float (~fs-rate crosstalk pickup) — connecting SCKI woke it instantly,
no power cycle needed.

## Phase 3 — data into the ESP32

- [x] Wire: BCK → IO17, LRC → IO32, OUT → IO33.
- [x] Firmware: second I2S port as slave RX (Philips format, 24-in-32-bit
      slots, stereo), debug serial line printing frame level in dB.
- [x] Test: phone playing a sine tone into LIN/RIN via 3.5 mm.

**Checkpoint: PASSED 2026-07-14** — idle floor ~-85 dB both channels;
440 Hz sine from phone → -22.3/-21.8 dB L/R, rock steady, ~15 744 frames
per 500 ms window (≈31.25 kHz confirmed end-to-end). Frames flowing also
settled IO17 = silk `TXD` empirically (vendor pinout image listing IO5
twice was a typo). No ESP32 slave-RX alignment quirks observed. 3.5 mm
socket: tip→LIN, ring→RIN, sleeve→analog GND pin between LIN/RIN.

## Phase 4 — into the beat pipeline

Design changed from the original "mic/line sub-toggle" to a flat 4-source
Source setting (user request 2026-07-14): **CDJ / Mic / Tap / Line** — enum
values append-only (`MODE_LINE = 3`) so persisted settings survive upgrades;
"Manual" renamed to "Tap" everywhere ("tAP" on-device). Mic and Line share
all audio-mode behavior (tap anchor, range gate, lock/PLL) via
`mode_is_audio()`.

- [x] Sample rate per-source at runtime (31250 line-in / 32000 mic); mel
      filterbank re-setup on source switch (top band 15 kHz on line-in,
      under its 15.625 kHz Nyquist).
- [x] mic_task reads whichever I2S channel the Source selects (single
      reader; Phase 3's line_task removed). Line-in stereo is averaged to
      mono into the same ring buffer. Full pipeline reset on switch.
- [x] BPM frame-rate correction: BTrack hard-codes kFrameHz = 62.5, so
      line-in readings are scaled by 61.035/62.5 (×0.97656) at the consumer
      in mic_task — without this every line-in BPM would read 2.4 % high.
- [x] UI: web Source dropdown lists CDJ / Mic / Line / Tap; device menu
      cycles CdJ → Aud → tAP → LinE ("Mic" cannot render on 7-seg — no M —
      so the mic source keeps its Aud glyph). Normal-mode source bar:
      CDJ=top, tAP=middle, Mic=bottom, Line=top+bottom ("≡").
- [x] **Checkpoint: PASSED 2026-07-14** — "rock solid high confidence
      tracking" through line-in (v1.13.0). Only Phase 5 (button ladder +
      jack detect) remains.

## Phase 5 — button ladder + jack detect (the only rewiring phase, last)

- [ ] Rewire: buttons to resistor ladder on IO35 (levels: idle 3.3 V /
      select 2.27 V / tap 1.65 V / both 1.34 V); IO39 → jack switch contact.
- [ ] Firmware: ADC1 decode of 4 ladder levels (20 ms debounce window,
      N-consistent-reads style); jack-detect auto-switch to line-in.
- [ ] Flash and rewire together — old button wiring stops working the moment
      the ladder firmware runs.

**Checkpoint:** all button functions work (tap, select, both-held combos for
OTA/reset); plugging a 3.5 mm cable auto-switches source to line-in.

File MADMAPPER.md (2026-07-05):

# tapbox with MadMapper

MadMapper works with tapbox in two complementary ways:

1. **Ableton Link** — MadMapper follows (or drives) the shared Link tempo that tapbox broadcasts. This needs no configuration beyond turning Link on.
2. **OSC** — MadMapper sends OSC commands *to* tapbox (tap, set BPM, nudge, and so on) so you can trigger tapbox from cues, buttons, or timelines inside MadMapper.

You can use either on its own, or both together.

---

## Ableton Link

Ableton Link support is built into MadMapper. On the **Master** tab, under **Global BPM**:

1. Turn on **Ableton Link** (1). MadMapper joins the Link session on the network.
2. By default MadMapper acts as a *follower* in the session. If you want MadMapper to be able to set the session tempo as well, turn on **Enable Setting BPM** (2).
3. With tapbox powered on and connected to the same network, the **Peers** field (3) shows at least `1 peer`. The count is higher when other Link-enabled programs are also on the network.
4. The current session tempo appears in the **BPM** field (4). When **Enable Setting BPM** is on, the BPM slider adjusts the Link tempo directly; otherwise it is read-only and simply reflects the tempo tapbox is broadcasting.

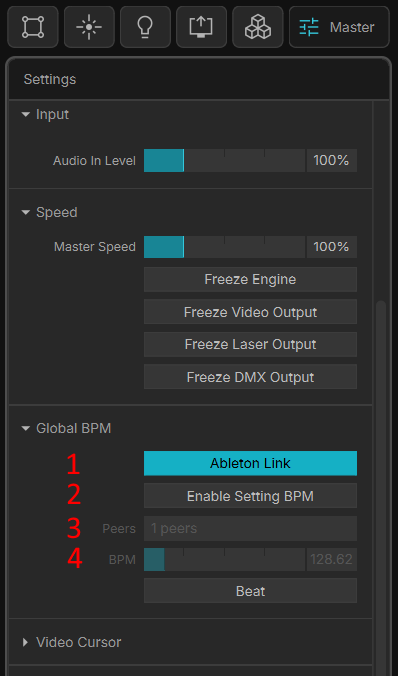
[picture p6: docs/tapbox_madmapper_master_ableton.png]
MadMapper Master tab — Ableton Link


That is all Ableton Link needs. From here, whenever you tap a tempo on tapbox, MadMapper follows instantly.

---

## Sending OSC to tapbox

MadMapper's OSC modules can send specific commands to tapbox — the same commands listed in the **OSC Control** section of the [user manual](MANUAL.md#osc-control). This lets you trigger `/tap`, set a `/bpm`, nudge the phase, and more, from anywhere in your MadMapper project.

Setup is two steps: first tell MadMapper where tapbox lives on the network, then add an OSC module per command you want to send.

### 1. Define tapbox as an OSC output

Open **Preferences → Project → OSC** and add an entry under **OSC Outputs** (the **+** button on the right):

| Field | Value |
|---|---|
| Name (1) | `tapbox` (any label you like) |
| Bonjour | `Custom` |
| IP (2) | tapbox's IP address (e.g. `192.168.1.117`) |
| Port | `8000` — tapbox always listens for OSC on UDP 8000 |

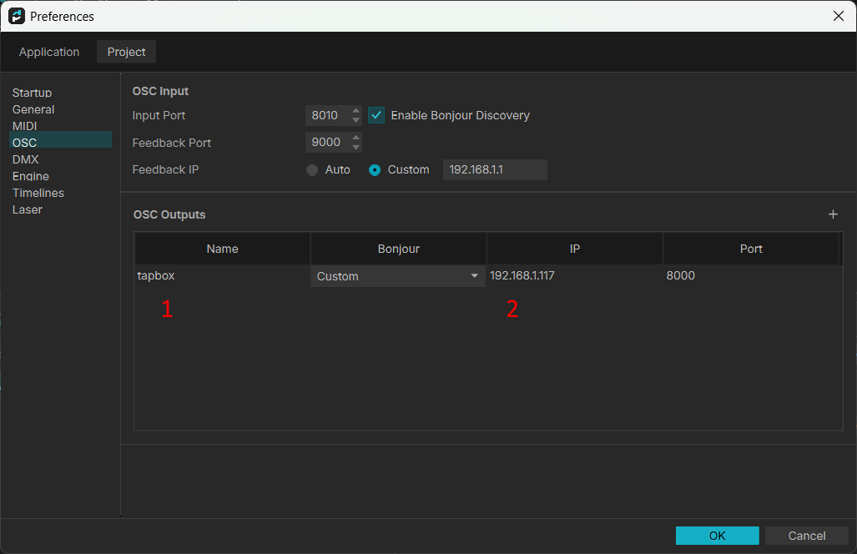
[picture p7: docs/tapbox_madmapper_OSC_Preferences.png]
MadMapper OSC preferences


The markers in the image call out the two fields that identify tapbox: its **Name** (1) and its **IP** address (2). Leave the **OSC Input** settings at the top of the dialog at their defaults — they are not needed to send commands to tapbox.

> Find tapbox's IP address on its display at boot — it scrolls the connection type and address (for example Eth `192.168.1.117`). If the address changes between sessions, give tapbox a static IP (set Lan. to Stat on the device, then enter the address on the web config page's Network tab — see the manual) so this entry never needs updating.

### 2. Add an OSC Out module per command

On the **Modules** tab, add a module instance and set its **Module** type to **OSC Out**. Configure it:

- **Target → Device** (1): choose the `tapbox` output you defined in Preferences.
- **Target → Address** (2): the OSC address of the command, e.g. `/tap`, `/bpm`, `/nudge`.
- **Event → Event Type** (3): pick the payload type the command expects — `Nil` for commands that take no argument (like `/tap` or `/downbeat`), or a numeric type for commands that take a value (like `/bpm` or `/signature`).
- **Trigger** (4): use **Send Now** to fire the command manually, or **Send On Value Change** to drive it from a control, timeline, or mapped surface.

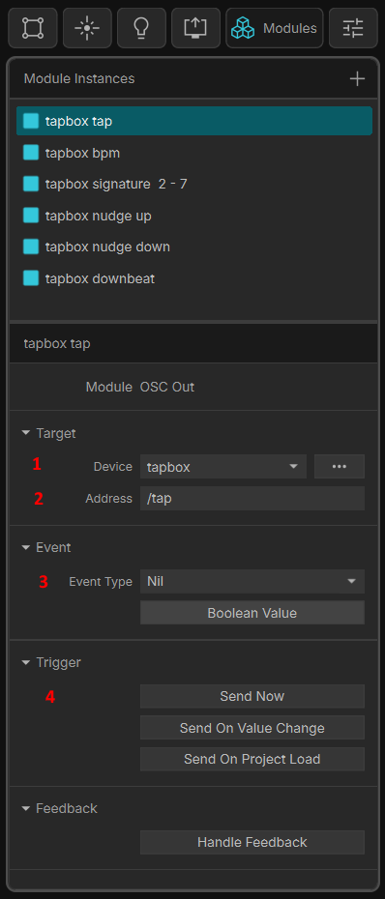
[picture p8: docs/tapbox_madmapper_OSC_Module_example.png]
MadMapper OSC module example


Create one module per command you want to control. A typical set mirrors the tapbox OSC command list:

| Module name | Address | Event Type | Notes |
|---|---|---|---|
| tapbox tap | `/tap` | Nil | Same as pressing the tap button |
| tapbox bpm | `/bpm` | Float/Int  | Set tempo to a specific BPM |
| tapbox signature | `/signature`  | Int (2–7)  | Change the time signature |
| tapbox nudge | `/nudge` | Float/Int (ms) | Shift phase by `ms` (+ = forward, − = back); no argument = 20 ms |
| tapbox downbeat | `/downbeat` | Nil | Reset the downbeat to this moment |

Once these exist you can map them to buttons, faders, or timeline cues anywhere in MadMapper.

---

## Tips

- **Link and OSC together:** use Ableton Link so MadMapper always displays and follows the live tempo, and use OSC modules for the actions Link doesn't cover — tapping a fresh tempo, forcing a downbeat, or nudging the phase.
- **Multicast between WiFi and Ethernet:** Ableton Link uses UDP multicast. Some routers don't bridge multicast between WiFi and Ethernet, so if MadMapper shows `0 peers`, put MadMapper and tapbox on the same interface (both Ethernet, ideally).
- **Static IP keeps OSC stable:** because the OSC output points at a fixed IP, giving tapbox a static address means your MadMapper project keeps working across reboots without re-entering the address.

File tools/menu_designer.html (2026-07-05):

# tapbox Display Designer

Segment-accurate mock of the 8-digit MAX7219 display, matching include/max7219.h and the CH_* glyph table in src/main.cpp. Click segments to toggle, or use the controls below. Use it to author/preview kMenuLabels-style rows or to rebuild figures like docs/display.jpg.

## Quick text

Apply across 8 digits → Clear all supports 0-9, a A b B C d e F h I J L n o P r S t u v, space (blank), - (dash), . (attaches to previous digit)

Load docs/display.jpg example Load "Beat" menu label Show annotation labels/arrows

## Appearance

Background Segment ON Segment OFF Label text

## Digits

## Export

Copy as C++ array Download

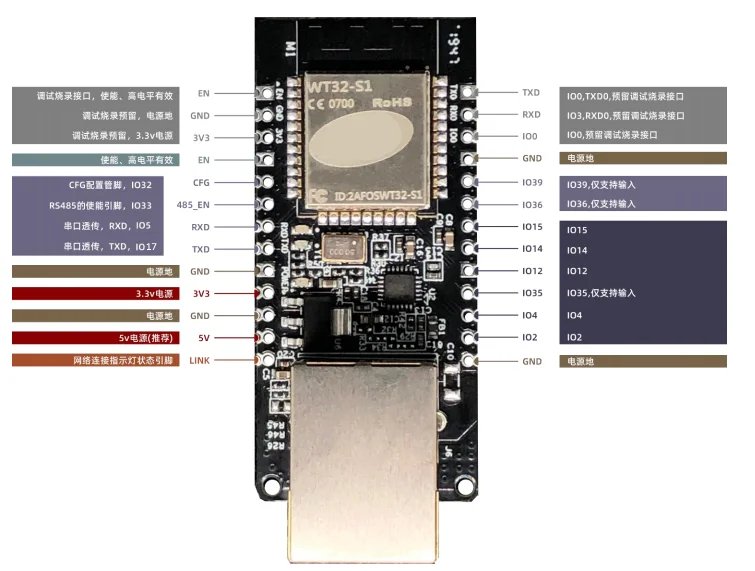
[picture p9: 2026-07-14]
component_images/wt32-eth01_pinout.png

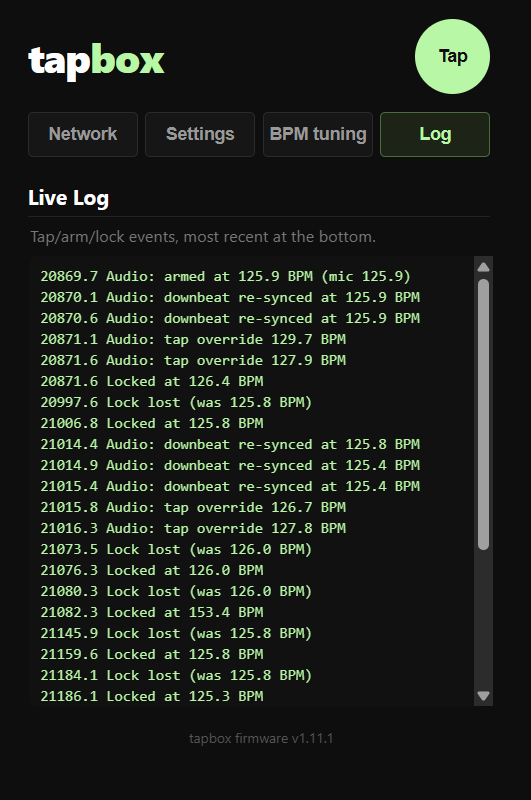
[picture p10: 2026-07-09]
docs/tapbox_web_config_log.png

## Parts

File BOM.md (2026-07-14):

# tapbox — Bill of Materials

All prices are approximate AliExpress retail at time of writing. Quantities are per unit.

## Components

| Component | Description | Qty | Unit price | Link |
|---|---|-----|---|---|
| WT32-ETH01 | ESP32 + LAN8720A Ethernet module (MCU) | 1 | $8.00 | [AliExpress](https://www.aliexpress.com/item/1005006900909314.html) |
| MAX7219 display | 8-digit 7-segment LED display module | 1 | $3.56 | [AliExpress](https://www.aliexpress.com/item/1005006242930158.html) |
| INMP441 | I2S MEMS microphone (Audio source) | 1 | $3.00 | [AliExpress](https://www.aliexpress.com/item/1005009648491391.html) |
| TENSTAR PCM1808 | Audio Stereo ADC 24bit input & Amplifier Board Player | 1 | $4.02 | [AliExpress](https://www.aliexpress.com/item/1005008885079639.html) |
| 26650 Li-ion cell | 3.7 V rechargeable battery | 1 | $10.00 | [AliExpress](https://www.aliexpress.com/item/1005011871986176.html) |
| TP4056 charger board | USB Li-ion charge/protection module | 1 | $2.87 | [AliExpress](https://www.aliexpress.com/item/1005009566821602.html) |
| sanwa button OBSF 30 black | Tap button (momentary, illuminated) | 1 | $6.00 | [AliExpress](https://www.aliexpress.com/item/33029461114.html) |
| mini Switch Push Button | Select button | 1 | $0.50 | [AliExpress](https://www.aliexpress.com/item/1005006384754591.html) |
| 3.5mm stereo socket with nut| With NC selector switch | 1 | $0.80 | [AliExpress](https://www.aliexpress.com/item/1005007571963236.html) |
| Rocker switch | Power switch | 1 | $0.40 | [AliExpress](https://www.aliexpress.com/item/1005009714438836.html) |
| Battery terminals | (pair) | 1 | $0.57 | [AliExpress](https://www.aliexpress.com/item/1005007470740046.html) |
| Resistor 10 kΩ | Pull-ups for IO35 / IO39 buttons | 2 | $0.01 | — |

**Device total: ~$39.74** (with CP2102 programmer: ~$44.16)

## Development tool

| Tool | Description | Price | Link |
|---|---|---|---|
| CP2102 USB programmer | USB–serial for initial flashing | $4.42 | [AliExpress](https://www.aliexpress.com/item/1005007551001958.html) |

The programmer is a one-time purchase — once the firmware is installed, OTA updates replace it.

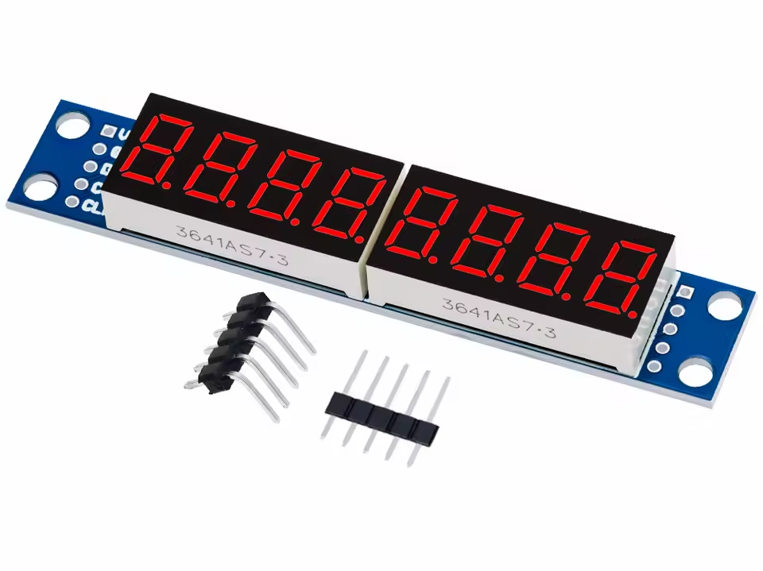
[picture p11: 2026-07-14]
component_images/max7219_8_digit_numeric_display.png

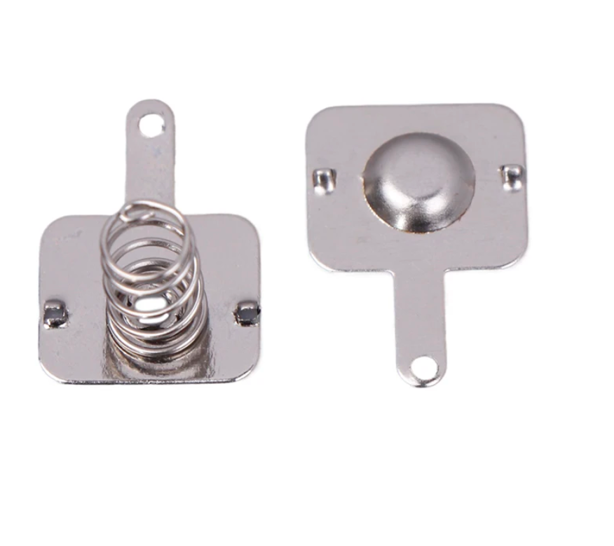
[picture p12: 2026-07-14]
component_images/battery_terminals.png

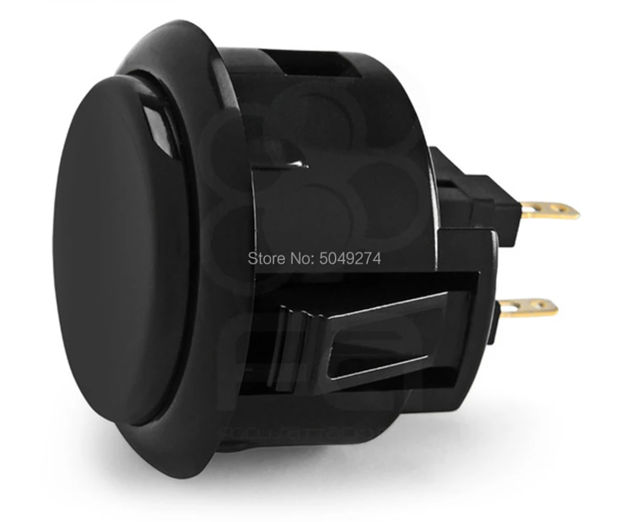
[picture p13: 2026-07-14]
component_images/Sanwa Button OBSF 30 OBSF24.png

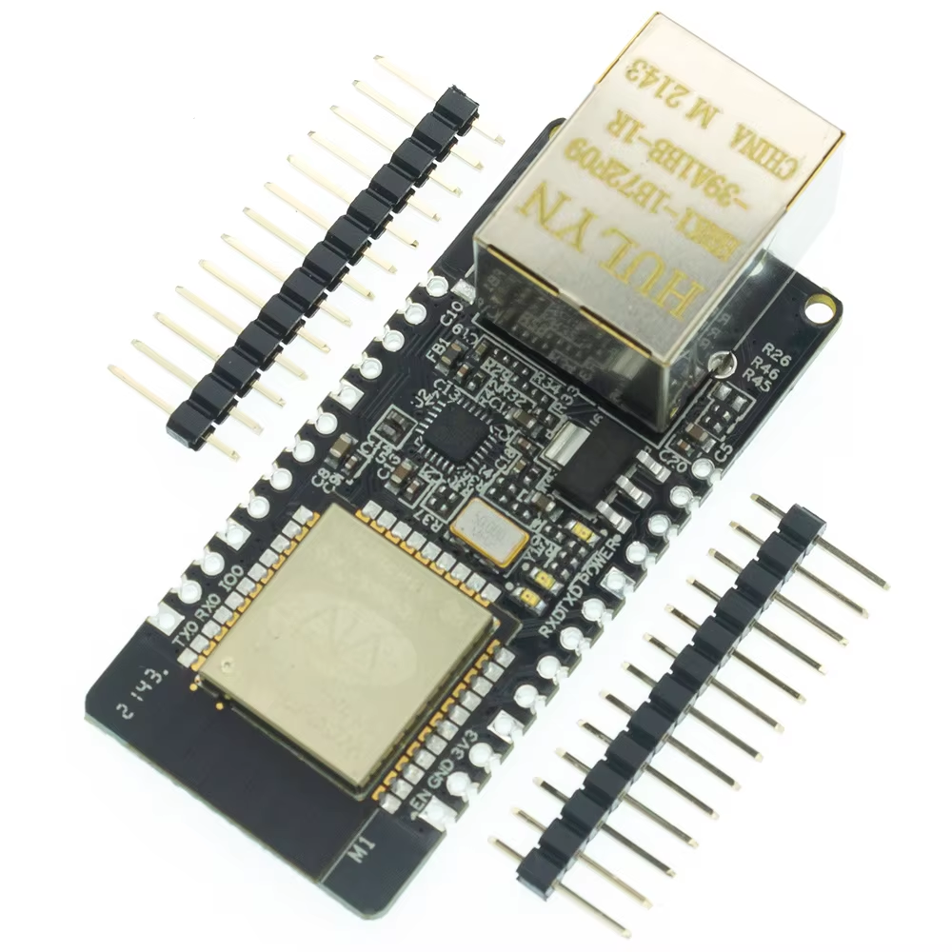
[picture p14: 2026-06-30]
component_images/wt32-eth01_part.png

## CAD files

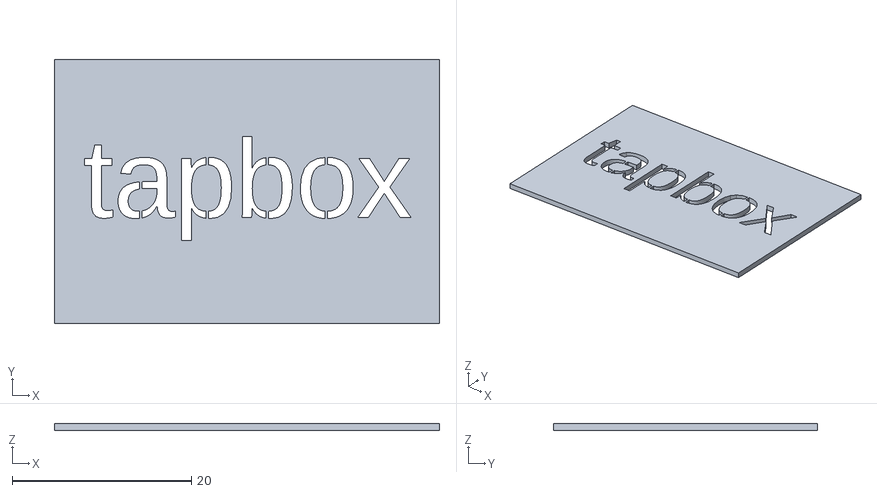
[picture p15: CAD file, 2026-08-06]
case/tapbox_case_label.stl
43.0 x 29.5 x 0.8

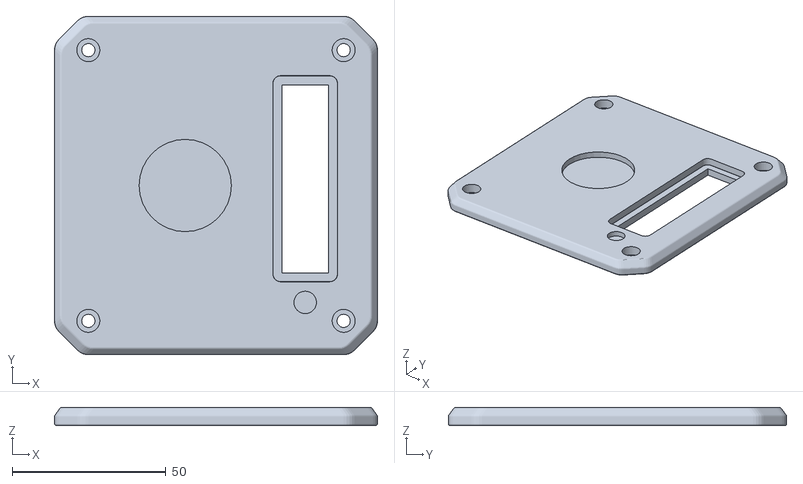
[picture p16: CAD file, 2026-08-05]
case/tapbox_case_lid.stl
105.0 x 110.0 x 6.00

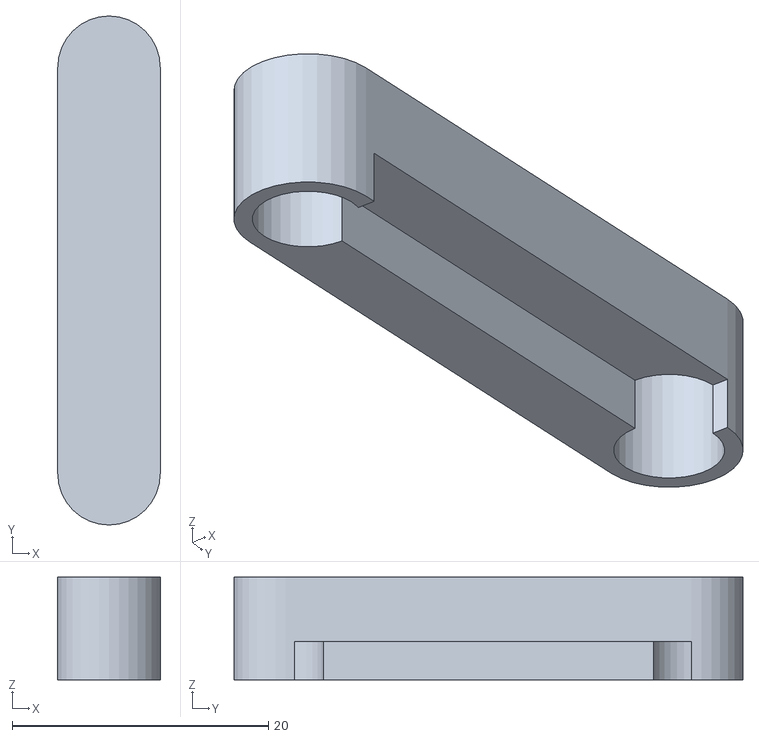
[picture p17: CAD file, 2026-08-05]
case/tapbox_case_WT32_bracket.stl
8.00 x 39.7 x 8.00

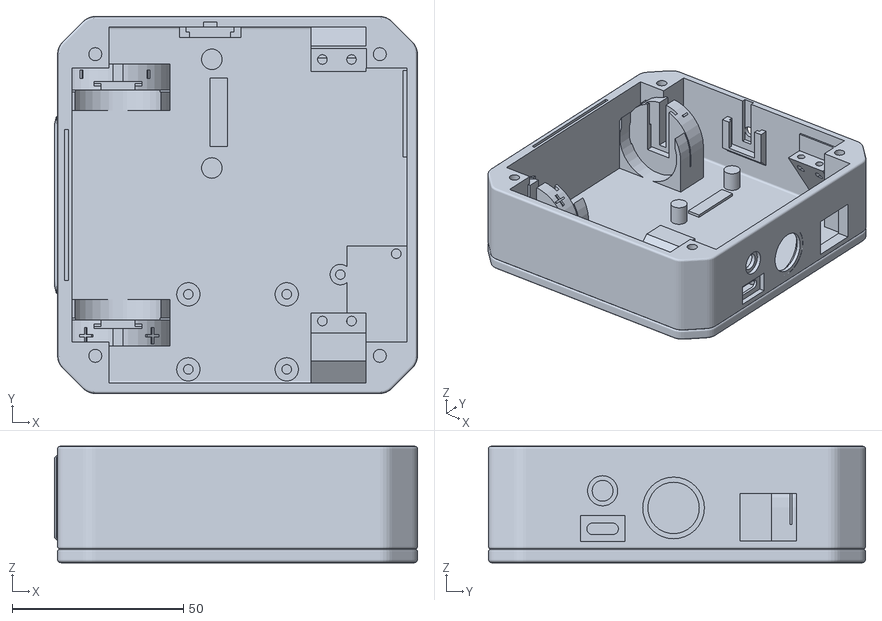
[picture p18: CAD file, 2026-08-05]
case/tapbox_case_base.stl
105.9 x 110.0 x 34.0

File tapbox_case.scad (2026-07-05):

use <boards.scad>

$fn=32;

width = 105;
length = 110;
height = 40;
cr = 10;
er = 1.5;
thickness = 3;


module tube(outer_radius=10, inner_radius=8, height=20){
    difference(){
        cylinder(r=outer_radius, h=height);
        translate([0,0,-1]) cylinder(r=inner_radius, h=height + 2);
    }
}

module donut(radius=10, height=2){
    r = height * 0.5;
    rotate_extrude(angle=360) translate([radius - r,0,0]) circle(d=height);
}

module round_rounded_rect(width, length, height, corner_radius, edge_radius){ 
    w = width * 0.5;
    l = length * 0.5;
    h = height * 0.5;
    hull(){
        translate([-w+corner_radius, -l+corner_radius,0]) donut(corner_radius, edge_radius*2);
        translate([-w+corner_radius, l-corner_radius,0]) donut(corner_radius, edge_radius*2);
        translate([w-corner_radius, -l+corner_radius,0]) donut(corner_radius, edge_radius*2);
        translate([w-corner_radius, l-corner_radius,0]) donut(corner_radius, edge_radius*2);
    }
}

module round_rounded_cube(width, length, height, corner_radius, edge_radius){
    hull(){
        translate([0,0,er]) round_rounded_rect(width, length, er*2, cr, er);
        translate([0,0,height - er]) round_rounded_rect(width, length, er*2, cr, er);
    }
}

module case_base(){
    t = thickness;
    w = width * 0.5;
    l = length * 0.5;
    difference(){
        union(){
            round_rounded_cube(width, length, 5, cr, er);
            translate([0,0,4.5]) round_rounded_cube(width, length, 31.5, cr, er);
        }
        difference(){
            translate([0,0,t]) round_rounded_cube(width-t-t, length-t-t, 50, cr-t, er);
            // remove parts so it gets left behind
            
            //  corner posts
            translate([-w+t,-l+t,0]) cube([12,12,height]);
            translate([-w+t,l-t-12,0]) cube([12,12,height]);
            translate([w-t-12,-l+t,0]) cube([12,12,height]);
            translate([w-t-12,l-t-12,0]) cube([12,12,height]);
            
            //  extra thickness for LAN port
            translate([w-t-1.3,14,0]) cube([2,25.2, 23]);
            
            //  posts for display board
            translate([21.5,56.5,0]) rotate([30,0,0]) cube([16, 10, 40]);
            translate([21.5,-66,14]) rotate([-45,0,0]) cube([16, 14, 40]);
        }
        
        //  Bolt holes
        translate([-w+cr, -l+cr,t]) cylinder(d=4.6, h=height);
        translate([-w+cr, l-cr,t]) cylinder(d=4.6, h=height);
        translate([w-cr, -l+cr,t]) cylinder(d=4.6, h=height);
        translate([w-cr, l-cr,t]) cylinder(d=4.6, h=height);
        
        //  RJ 45 hole
        translate([-7.2,14,thickness+2]) wt32_eth01(cut=true);
        
        //  USB C hole
        translate([49.3,-39,thickness+4]) rotate([0,0,90]) TP4056(cut=true);
        translate([55.5,-21.7,t+7]) cube([10,13,7.5], center=true);
             
        // Hole for power switch
        translate([46.1,0,thickness + 8]) switch(cut=true);
        
        //  Flat area for display board
        translate([29.0,4.15,41]) cube([17, 83, 20], center=true);
        
        //  Flat area for menu button
        translate([29.0,-40,44.5]) cube([17, 14, 20], center=true);
        
        //  Mounting holes for Display board
        translate([29, 2.15,31]) rotate([0,0,-90]) 8_digit_7_segment_max9219_display_module_holes();
        
        //  Foot pad recesses
        translate([-w+cr, -l+cr,-1]) cylinder(d=8.8, h=2);
        translate([-w+cr, l-cr,-1]) cylinder(d=8.8, h=2);
        translate([w-cr, -l+cr,-1]) cylinder(d=8.8, h=2);
        translate([w-cr, l-cr,-1]) cylinder(d=8.8, h=2);
        
        // Microphone hole and slot
        translate([0, 50.4,thickness+10]) rotate([0,0,90]) inmu441_microphone_holder(cut=true);
    }
    
    //  lock bracket mounting posts for WT32 board
    translate([-7.5,10.8,0]) cylinder(d=6, h=7+thickness);
    translate([-7.5,42.5,0]) cylinder(d=6, h=7+thickness);
      
    //  Lock and support for tp4056 board
    translate([30.0,-20.3,0]) tube(3, 1.4, 4+thickness);
    difference(){
        translate([33,-40,thickness]) cube([17.4,28,4]);
        //  Mounting hole for TP4056
        translate([46.3,-14.2,-1]) cylinder(d=2.8, h=6+thickness);
    }
   
    //  Battery holder
    translate([-36,-34.5,t]) rotate([0,0,90]) 26650_battery_bulkhead();
    translate([-36,34.5,t]) rotate([0,0,-90]) 26650_battery_bulkhead();
    
    // microphone holder
    translate([0, 50.4,thickness+10]) rotate([0,0,90]) inmu441_microphone_holder();
    
    //  Marking on off switch
    translate([52,5,thickness + 11]) rotate([90,0,90]) linear_extrude(1) text("1", size=4);
    translate([52,-8,thickness + 11]) rotate([90,0,90]) linear_extrude(1) text("0", size=4);
}

module lid(){
    t = thickness;
    w = width * 0.5;
    l = length * 0.5;
    difference(){
        round_rounded_cube(width, length, 5, cr, er);
        //  Bolt holes
        translate([-w+cr, -l+cr,-1]) cylinder(d=5.1, h=height+2);
        translate([-w+cr, l-cr,-1]) cylinder(d=5.1, h=height+2);
        translate([w-cr, -l+cr,-1]) cylinder(d=5.1, h=height+2);
        translate([w-cr, l-cr,-1]) cylinder(d=5.1, h=height+2);
        
        //  Bolt recess
        translate([-w+cr, -l+cr,1.61]) cylinder(d=9.5, h=3.4);
        translate([-w+cr, l-cr,1.61]) cylinder(d=9.5, h=3.4);
        translate([w-cr, -l+cr,1.61]) cylinder(d=9.5, h=3.4);
        translate([w-cr, l-cr,1.61]) cylinder(d=9.5, h=3.4);

        //  display slot
        translate([29, 2.15,-2]) rotate([0,0,-90]) 8_digit_7_segment_max9219_display_module(cut=true);
        
        //  tap button slot
        translate([-10,0,-27]) push_button(cut=true);
        
        //  menu button cutout
        translate([29,-38,-0.8]) menu_switch(cut=true);
        
        //  Branding
        translate([-43,0,5.0-0.6]) rotate([0,0,-90]) linear_extrude(2) text("TapBox", size=8, halign="center", valign="center",spacing=1, direction="ltr", language="en", script="latin");
    } 
    //  Lid bracing
    //translate([10,0,-2.5]) cube([4, width-t-t-0.5, 5], center=true);
    //translate([-29,0,-2.5]) cube([4, width-t-t-0.5, 5], center=true);
}

module switch(cut = false){
    t = cut? 6: 0.3;
    d = cut? 3: 2.5;
    cube([6.9, 15.5, 7.3], center=true);
    
    translate([3.45, 0, 0]) difference(){
        translate([-t*0.5, 0,0]) cube([t, 23.3, 7.3], center=true);
        translate([0, 9.5, 0]) rotate([0,90,0]) cylinder(d=d,h=2.3, center=true);
        translate([0, -9.5, 0]) rotate([0,90,0]) cylinder(d=d,h=2.3, center=true);
    }
    // peg
    translate([7.1, 0, 0]) cube([7.3, 5.3, 3.7], center=true);
    if (cut){    
        translate([7.1, 0, 0]) cube([7.3, 10, 4], center=true);
        translate([4.0, 9.5, 0]) rotate([0,90,0]) cylinder(d=d,h=10, center=true);
        translate([4.0, -9.5, 0]) rotate([0,90,0]) cylinder(d=d,h=10, center=true);
    }
}

module inmu441_microphone_holder(cut = false){
    if (cut){
        //  microphone hole
        translate([1.6-0.1,8,8]) rotate([0,90,0]) cylinder(d=4, h=10);
        //  Groove for components to clear
        translate([1.6-0.1,6,4]) cube([2,4,16]);
    } else {
        difference(){
            cube([2,16,12]);
            translate([0.6,1,1]) cube([1,14,16]);
            translate([-2+1,1.5,1]) cube([2,13,16]);
            //  Groove for components to clear
            translate([1.6 - 0.1,6,4]) cube([3,4,16]);
        }
    }
}

module push_button(cut=false){
    w = cut? 24.1 : 23.8;
    l = cut? 18.3 : 18;
    d = cut? 16.0 : 15.7;
    cylinder(d=d, h=31);
    translate([-9, -11.9, 30]) cube([l, w, 10.2]);
}

module battery(radius=26.3){
    translate([0,0,13.15]) rotate([90, 0,0]) cylinder(d=radius, h=66, center=true);
}

module menu_switch(cut=false){
    d = cut? 7.3 : 6.7;
    h = cut? 10 : 3.6;
    s = cut? 12.15 : 12;
    g = cut? 0.2 : 0; //  Gap between round and square bit makes pringint easier. Scrificial layer technique
    translate([0,0,3.1*0.5]) cube([s,s,3.1], center=true);
    translate([0,0,3.1+ g]) cylinder(d=d, h=h);
}

module wt32_bracket(){
    difference(){
        hull(){
            translate([-7.5,10.8,0]) cylinder(d=6+2, h=5+thickness);
            translate([-7.5,42.5,0]) cylinder(d=6+2, h=5+thickness);
        }

        translate([-7.5,10.8,0]) cylinder(d=6, h=4+thickness);
        translate([-7.5,42.5,0]) cylinder(d=6, h=4+thickness);
        
        translate([-7.5, 11.5, -2]) cube([10, 31, 5]);
    }
}
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

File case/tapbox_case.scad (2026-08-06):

use <boards.scad>
use <pathbuilder.scad>

$fn=32;

width = 105;
length = 110;
height = 40;
cr = 5;
ser = 0.75;
ber = 1.0;
chamfer = 6;
thickness = 3;
bolt_offset = 11;
lid_height = 6;
bolt_head = 7.5;//9;
bolt = 3.8;//4.6;

module tube(outer_radius=10, inner_radius=8, height=20){
    difference(){
        cylinder(r=outer_radius, h=height);
        translate([0,0,-1]) cylinder(r=inner_radius, h=height + 2);
    }
}

module ledge(height=4, width=2, length=10){
    rotate([90,0,90]) linear_extrude(length) M(0,-height)
    v(height)
    h(width);
}

module donut(radius=10, height=2){
    r = height * 0.5;
    rotate_extrude(angle=360) translate([radius - r,0,0]) circle(d=height);
}

module round_rounded_rect(width, length, corner_radius, edge_radius){ 
    w = width * 0.5;
    l = length * 0.5;
    hull(){
        translate([-w+corner_radius, -l+corner_radius,0]) donut(corner_radius, edge_radius*2);
        translate([-w+corner_radius, l-corner_radius,0]) donut(corner_radius, edge_radius*2);
        translate([w-corner_radius, -l+corner_radius,0]) donut(corner_radius, edge_radius*2);
        translate([w-corner_radius, l-corner_radius,0]) donut(corner_radius, edge_radius*2);
    }
}

module round_chamfered_rect(width, length, chamfer, corner_radius, edge_radius){
    w = width * 0.5;
    l = length * 0.5;
    hull(){
        translate([-w+corner_radius, -l+corner_radius + chamfer,0]) donut(corner_radius, edge_radius*2);
        translate([-w+corner_radius + chamfer, -l+corner_radius,0]) donut(corner_radius, edge_radius*2);
        
        translate([-w+corner_radius + chamfer, l-corner_radius,0]) donut(corner_radius, edge_radius*2);
        translate([-w+corner_radius, l-corner_radius - chamfer,0]) donut(corner_radius, edge_radius*2);
        
        translate([w-corner_radius - chamfer, -l+corner_radius,0]) donut(corner_radius, edge_radius*2);
        translate([w-corner_radius, -l+corner_radius + chamfer,0]) donut(corner_radius, edge_radius*2);
        
        translate([w-corner_radius - chamfer, l-corner_radius,0]) donut(corner_radius, edge_radius*2);
        translate([w-corner_radius, l-corner_radius - chamfer,0]) donut(corner_radius, edge_radius*2); 
    }
}

module round_rounded_cube(width, length, height, corner_radius, bottom_edge_radius, top_edge_radius){
    hull(){
        translate([0,0,bottom_edge_radius]) round_rounded_rect(width, length, corner_radius, bottom_edge_radius);
        translate([0,0,height - top_edge_radius]) round_rounded_rect(width, length, corner_radius, top_edge_radius);
    }
}

module round_chamfered_cube(width, length, height, chamfer, corner_radius, bottom_edge_radius, top_edge_radius){
    hull(){
        translate([0,0,bottom_edge_radius]) round_chamfered_rect(width, length, chamfer, corner_radius, bottom_edge_radius);
        translate([0,0,height - top_edge_radius]) round_chamfered_rect(width, length, chamfer, corner_radius, top_edge_radius);
    }    
}

module case_base(){
    t = thickness;
    w = width * 0.5;
    l = length * 0.5;
    difference(){
        union(){
            round_chamfered_cube(width, length, 4, chamfer, cr, ber, ser);
            translate([0,0,4]) round_chamfered_cube(width, length, height-4-lid_height, chamfer, cr, ser, ser);
            translate([-51.4,0,20]) rotate([90,0,-90]) hull(){
                translate([0,-1,1]) round_rounded_rect(width=52, length=25, corner_radius=2.5, edge_radius=0.5);
                translate([0,-1,1.5]) round_rounded_rect(width=48, length=24, corner_radius=2.5, edge_radius=0.5);
            }
        }
        difference(){
            translate([0,0,t]) round_chamfered_cube(width-t-t, length-t-t, 50, chamfer, cr-t, ser, ser);
            // remove parts so it gets left behind
            
            //  corner posts
            translate([-w+t,-l+t,0]) cube([12,12,height]);
            translate([-w+t,l-t-12,0]) cube([12,12,height]);
            translate([w-t-12,-l+t,0]) cube([12,12,height]);
            translate([w-t-12,l-t-12,0]) cube([12,12,height]);
            
            //   Branding slot rail
            translate([-49.5,-40, thickness]) cube([1.2, 80, height-thickness-lid_height]);
            //translate([-49.3,18.5, thickness]) cube([1.2, 9, height-thickness-lid_height-4]);
            
            //  extra thickness for LAN port
            translate([w-t-1.3,14,0]) cube([2,25.2, 23]);
            
            //  posts for display board
            translate([21.5,56.5,0]) rotate([33,0,0]) cube([16, 10, 40]);
            translate([21.5,-66,14]) rotate([-47,0,0]) cube([16, 14, 40]);
        }
        
        //  Bolt holes
        translate([-w+bolt_offset, -l+bolt_offset,t]) cylinder(d=bolt, h=height);
        translate([-w+bolt_offset, l-bolt_offset,t]) cylinder(d=bolt, h=height);
        translate([w-bolt_offset, -l+bolt_offset,t]) cylinder(d=bolt, h=height);
        translate([w-bolt_offset, l-bolt_offset,t]) cylinder(d=bolt, h=height);
        
        //  RJ 45 hole
        translate([-7.2,14,thickness+2]) wt32_eth01(cut=true);
        
        //  USB C hole
        translate([49.3,-39,thickness+4]) rotate([0,0,90]) TP4056(cut=true);
        translate([55.5,-21.7,t+7]) cube([10,13,7.5], center=true);
             
        // Hole for power switch
        //translate([46.1,0,thickness + 8]) switch(cut=true);
        translate([52.4,-1,thickness + 13]) rotate([0,90,0]) cylinder(d=18, h=5);
        translate([48,-1,thickness + 13]) rotate([0,90,0]) cylinder(d=18, h=3);
        translate([45,-1,thickness + 13]) rotate([0,90,0]) cylinder(d=15, h=15);
        
        //  Flat area for display board
        translate([29.0,4.15,37.0]) cube([17.1, 83, 20], center=true);
        
        //  Flat area for menu button
        translate([29.0,-40,44.0-0.9]) cube([17, 14, 20], center=true);
        
        //  Mounting holes for Display board
        translate([29, 2.15,31]) rotate([0,0,-90]) 8_digit_7_segment_max9219_display_module_holes();
        
        //  Foot pad recesses
        translate([-w+bolt_offset, -l+bolt_offset,-1]) cylinder(d=8.8, h=2);
        translate([-w+bolt_offset, l-bolt_offset,-1]) cylinder(d=8.8, h=2);
        translate([w-bolt_offset, -l+bolt_offset,-1]) cylinder(d=8.8, h=2);
        translate([w-bolt_offset, l-bolt_offset,-1]) cylinder(d=8.8, h=2);
        
        //  Microphone hole and slot
        translate([0, 50.4,thickness+10]) rotate([0,0,90]) inmu441_microphone_holder(cut=true);
        
        //  Audio jack hole
        translate([51.0,-21.7,21]) rotate([0,90,0]) cylinder(d=8.8, h=3);
        translate([49.0,-21.7,21]) rotate([0,90,0]) cylinder(d=6.1, h=10);
        
        //  Branding cutout
        translate([-51.4-1,0,19]) rotate([90,0,-90]) hull(){
            translate([0,0,-1.7]) round_rounded_rect(width=40, length=20, corner_radius=2.5, edge_radius=0.5);
            translate([0,0,2]) round_rounded_rect(width=42, length=21, corner_radius=2.5, edge_radius=0.5);
        }
        //  Branding card slot
        translate([-49.9,0,21+thickness-1]) rotate([0,0,-90]) cube([44, 1.1, 42], center=true);
    }
    
    //  support for WS32 board
    translate([-8, 17,0]) cube([5,20,thickness+1]);
    
    //  lock bracket mounting posts for WT32 board
    translate([-7.5,10.8,0]) cylinder(d=6, h=7+thickness);
    translate([-7.5,42.5,0]) cylinder(d=6, h=7+thickness);
      
    //  Lock and support for tp4056 board
    translate([30.0,-20.3,0]) tube(3, 1.4, 4+thickness);
    difference(){
        translate([32,-40,thickness]) cube([18.4,28,4]);
        //  Mounting hole for TP4056
        translate([46.3,-14.2,-1]) cylinder(d=2.8, h=6+thickness);
    }
    
    //  Mounting points for PCM1808 board
    translate([0,-37,thickness + 4]) PCM1808(studs=true, height=4);
   
    //  Battery holder 72.2
    translate([-34.9,-36.1,t]) rotate([0,0,-90]) 26650_battery_bulkhead("+");
    translate([-34.9,36.1,t]) rotate([0,0,90]) 26650_battery_bulkhead("-");
    
    // microphone holder
    translate([0, 50.4,thickness+10]) rotate([0,0,90]) inmu441_microphone_holder();
    translate([1, 50.4+2.0,thickness+10]) rotate([0,0,180]) ledge(3, 3, 18);
    
    //  Marking on off switch
    //translate([52,5,thickness + 11]) rotate([90,0,90]) linear_extrude(1) text("1", size=4);
    //translate([52,-8,thickness + 11]) rotate([90,0,90]) linear_extrude(1) text("0", size=4);
    
     //  Branding
     //translate([-50,0,20]) rotate([90,0,-90]) linear_extrude(0.7) text("tapbox", size=8, halign="center", valign="center",spacing=1, direction="ltr", language="en", script="latin");
}
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

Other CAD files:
case/display_cover_tapbox.FCStd

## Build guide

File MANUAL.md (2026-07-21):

# tapbox User Manual

---

## What Is tapbox?

tapbox is a compact, dedicated tempo controller for musicians and live performers who use Ableton Link. It sits on your desk or in your rack, connects to your network via Ethernet or WiFi, and keeps every device in your setup locked to the same beat — without you having to touch a laptop.

The idea is simple: tap the button on the beat to set your tempo, and tapbox broadcasts it to every Link-enabled device on the network. Your Ableton Live session, Resolume, MadMapper, LaserOS, your iOS apps, your hardware synths with Link support — they all lock in instantly. From that point on you can send commands from a phone or tablet over OSC if you prefer to stay hands-free.

tapbox is always on, always listening, and always in sync.

---

## Getting to Know Your tapbox

### The Display

tapbox uses an 8-digit display that shows you everything you need at a glance.

Display layout

Reading left to right:

- **beat** — the current tempo in BPM (`120.0`), updated in real time when any device in the Link session adjusts it
- **count** — which beat of the bar you are on right now (advances with the music)
- **lock dot** — the decimal point on the count digit: **solid** = locked (CDJ active / audio stable / tap set); **blinking** = Mic or Line source listening but not yet stable; **off** = no lock
- **source bar** — horizontal segments just after the count digit show which source is active: **top = CDJ**, **middle = Tap**, **bottom = Mic**, **top + bottom = Line**
- **peers** — how many other Ableton Link peers are connected to the session

On startup, tapbox joins the existing Link session tempo if one is already running, otherwise it starts at 120 BPM. You can tap a new tempo whenever you are ready.

### The Controls

tapbox has two buttons:

**Tap button** — the main button. Tap it in time with your music to set the tempo. A single tap immediately defines the downbeat (first beat of the bar). Three more taps locks in the tempo. In the menu, pressing tap moves to the next item or increments a value — hold it to auto-increment.

**Select button** — the confirm button. A short press enters the menu from normal mode, steps into an edit field, or confirms a value. Hold it for one second to go back or exit the menu. Hold select for 1 second to cancel.

---

## Setting the Tempo

Tap the tap button in rhythm. The downbeat for the Link session is immediately defined by the first tap. It takes three more taps before tapbox starts to adjust the tempo of the Link session. The current tempo and beat progress is displayed live at all times.

You do not have to be perfectly precise. tapbox averages the timing across all your taps, so the more taps in sequence, the more accurate the reading becomes.

After you are locked in, any further taps continue to refine the tempo. tapbox considers the session established when you stop tapping for two seconds. Simply start tapping again to define a new tempo.

---

## Sync Sources

tapbox can get its tempo four different ways. You pick one with the Src menu item, and the active source is shown by a bar on the display (top = CDJ, middle = Tap, bottom = Mic, top + bottom = Line).

### Tap (`tAP`)

Classic tap tempo, exactly as described above. You are in full control — tap four times to set the tempo and the downbeat.

### Mic (`Aud`)

A small microphone listens to the room and works out the tempo for you, while **you** tap the downbeat. This is the hybrid mode: the machine handles the BPM, you handle the musical "beat 1".

How to use it:

1. Switch Src to Aud. The bottom bar lights up. Nothing happens to the tempo yet — the mic is just listening.
2. Play the music near the microphone.
3. **Tap once on the beat** to accept the detected tempo and set the downbeat to that moment — or **tap four times** if you want to set the tempo yourself and let the mic refine it from there.
4. The beat digit's decimal point **blinks** while the mic is searching for a stable lock, then goes **solid** once locked. From then on the tempo tracks the music automatically; a single tap any time re-aligns the downbeat without changing the tempo.

The detector analyzes the full spectrum via an FFT/mel-filterbank pipeline rather than a single frequency band, so it isn't limited to a specific kick sound. The web config page's BPM tuning tab carries a live diagnostic chart plus four sliders that tune the detector's sensitivity to your source and room, and how far you trust it to refine your tap — see **Audio Tuning** below, and the technical write-up in `BEAT_DETECTION.md` for how it works.

### Line (`LinE`)

The same hybrid beat detection as Mic, but fed directly from the **3.5 mm line input** instead of the microphone — plug in a feed from your mixer (booth/aux/record out), a media player, or a phone.

Everything works exactly as described for Mic: tap once to accept the detected tempo and set the downbeat, tap four times to override. The difference is the signal quality: line-in hears the music electrically, so there is no room noise, no chatter from the audience, and no acoustic delay between the speakers and a microphone. If a line feed is practical in your setup, prefer it over the mic — it locks faster and holds through quiet passages that would starve the microphone.

Switching between Mic and Line resets the detector, so re-tap once after switching to re-anchor.

### CDJ (`Cdj`)

tapbox passively reads Pioneer Pro DJ Link beat packets off the network and feeds the CDJ's tempo straight into Ableton Link — no tapping needed. See the CDJ details below.

---

## Connecting to Your Network

### Ethernet

Plug a standard network cable into the Ethernet port before powering on. tapbox scrolls the connection type and assigned IP address across the display at startup — for example `Eth 192.168.1.55`. This tells you where to find it on the network for OSC control.

Ethernet is always preferred over WiFi. If both are available, tapbox uses Ethernet.

#### DHCP, AutoIP fallback, and traps

With Lan. left at the default Auto setting, Ethernet on tapbox is meant to work like a USB cable — plug it in and it just works. Most networks have a router that hands out an address automatically, and that's all tapbox needs.

Occasionally there's no router in the picture at all — for example, a cable run straight from tapbox to a CDJ player or a laptop's Ethernet port, with nothing else in between. There's nobody there to hand out an address, so tapbox assigns itself a temporary one starting with `169.254.` so it's still reachable. You don't need to do anything for this to happen.

> **Trap:** a `169.254.` address isn't guaranteed to be the final one. For about 2 minutes after it appears, tapbox keeps listening in case a proper router shows up late — if one does, tapbox switches to the address it offers and scrolls the new IP across the display, the same way it does at boot. If you jot down a `169.254.` address the moment it appears and hard-code it somewhere (an OSC destination, a saved shortcut) without noticing the display update a minute or two later, it may stop working.
>
> **Rule of thumb:** if the display shows a `169.254.` address, give it a couple of minutes to settle before writing it down. If you need an address that's guaranteed to never move, set Lan. to Stat instead (see below).

The DHCP/AutoIP race only restarts if the Ethernet cable is unplugged and re-seated (or tapbox reboots) — so re-seating the cable is also a reasonable first step if tapbox ever seems stuck on a stale address.

### WiFi

tapbox can connect to your WiFi network and run Ableton Link over it. This is useful when your performance space does not have an Ethernet switch nearby, or when you need to sync with a device that is on WiFi and your router bridges multicast between the two interfaces.

**The ESP32 radio supports 2.4 GHz only.** If your router has separate 2.4 GHz and 5 GHz networks (often shown as two different SSIDs, or a combined band with a single SSID), make sure you use the 2.4 GHz SSID when entering credentials.

#### First-time WiFi setup

1. Boot tapbox without an Ethernet cable plugged in.
2. tapbox creates a WiFi network called **tapbox** and scrolls `AP 192.168.4.1` followed by an 8-digit PIN across the display — the PIN fills the whole display and pauses there for 6 seconds so you have time to read it.
3. Connect your phone or laptop to the **tapbox** network, using that PIN as the WiFi password.
4. Open **http://192.168.4.1** in your browser. It will ask for a username and password — enter `tapbox` and the same PIN.
5. Enter your WiFi network name (SSID) and password. The SSID field is case-sensitive — copy it exactly from your phone's WiFi list.
6. Tap **Save Network — tapbox will reboot**. The device saves the credentials and reboots, then connects to your network as a WiFi client and scrolls `StA` followed by the assigned IP address.

The PIN is derived from the device's own hardware, so it's fixed for the life of that unit and never needs to be written down — it follows the IP address on the display at every boot or reconnect, in any mode (Ethernet, WiFi, or AP), and is always available from the Addr item in the menu.

> **What the PIN is for:** it exists to stop someone at a gig or in an office from wandering up to tapbox and casually changing your settings — it is not intended as strong security. Anyone determined enough to take the firmware apart could work out how the PIN is derived. Don't rely on it to protect anything beyond "keep the unsuspecting public out."

#### Changing WiFi credentials later

Unplug the Ethernet cable (or boot without one). If the stored credentials fail, tapbox falls back to AP mode automatically — connect to the **tapbox** network using its PIN and open **http://192.168.4.1** to update them.

#### Automatic Ethernet / WiFi switching

tapbox switches interfaces automatically without a reboot:

- **Ethernet plugged in** → tapbox stops WiFi and switches Link to Ethernet.
- **Ethernet unplugged** → tapbox starts WiFi (connecting to stored credentials, or starting the access point if none are stored).

If WiFi credentials fail to connect, tapbox falls back to AP mode immediately so you can reconfigure without rebooting.

By default tapbox uses DHCP. If you need a fixed address, set Lan. to Stat on the device and enter the IP/subnet/gateway on the web config page (see below) — this applies to whichever interface, Ethernet or WiFi, is actually active.

### Web Configuration Page

The config page is available at the device's IP address on port 80, from any browser over Ethernet or WiFi. Your browser will prompt for a username and password — enter `tapbox` and the 8-digit PIN that follows the IP address on the display (or via Addr in the menu). This applies every time, in every mode, since the page can change any setting on the device. A **Tap** button sits above the tabs and works from any of them — it's the same tap the physical button drives, useful for tapping tempo from a phone or laptop without reaching the device. The page below it is organized into four tabs — Network, Settings, and BPM tuning each have their own save button; the Log tab is view-only. Fields that don't apply to your current settings are greyed out rather than hidden, so the layout stays consistent.

Network tab

**Network** (WiFi SSID/password, network mode, static IP/subnet/gateway) — tap **Save Network — tapbox will reboot** to apply. The orange button is a reminder that a reboot follows. Network mode has three options — DHCP, Static, and Access Point — and static IP/subnet/gateway apply to whichever interface (Ethernet or WiFi) is active. The IP/Subnet/Gateway fields grey out unless Network Mode is Static.

Settings tab

**Settings** (time signature, source, brightness) — tap **Save Settings** to apply immediately. No reboot occurs; the device updates live and the page returns with a confirmation link.

BPM tuning tab

**BPM tuning** — audio beat-detector parameters plus a live chart of the incoming signal, described in full under **Audio Tuning** below. The whole tab greys out (controls disabled, chart dimmed) whenever the Source isn't Mic or Line, since these settings only affect audio detection.

**Log** — a fourth, view-only tab: a live scrolling log of tap/arm/lock events, timestamped, useful for testing without a serial cable attached (e.g. watching tempo-tracking behavior while changing pitch/speed in DJ software). Only active while the tab is open in a browser — see `BEAT_DETECTION.md` for what's logged.

---

## The Settings Menu

Press the select button to open the menu. Press the tap button to move between items. Press the select button to enter edit mode for the selected item, then press the tap button to change the value (hold for fast auto-increment). Press select again to confirm and return to the menu.

Menu mode example: Beat label with value 4

Each menu screen shows a 4-character label on the left, then the current value right-justified on the right — for example, Beat with a time signature of `4`.

To go back from an edit, hold the select button for one second. To exit the menu entirely, hold select or wait six seconds — tapbox returns to normal mode without saving the current edit. When you next open the menu it returns to the last item you were on.

---

### Beat — Time Signature

**What it does:** tells tapbox how many beats are in a bar.

The beat counter on the display counts from 1 up to this number, then loops back to 1. This keeps you visually oriented in the musical phrase.

**Available values:** 2, 3, 4, 5, 6, 7

**When to use it:** if you are playing a waltz in 3/4, set this to 3 so the counter runs 1–2–3 rather than counting to 4 and going out of sync with the phrase. For odd-time signatures like 7/8, set it to 7.

*Default: 4*

---

### Led — Display Brightness

**What it does:** adjusts how bright the display glows across four levels (1 – 4).

The display gives you a live preview as you change the value. In a dark venue, level 1 or 2 keeps it readable without becoming distracting. In a brightly lit studio, level 4 is easy to read from across the room.

*Default: 2*

---

### Src — Source

**What it does:** selects where tapbox gets its tempo. Four values:

- Cdj — Pioneer Pro DJ Link (see below)
- Aud — audio beat detection from the microphone (you tap the downbeat)
- `LinE` — audio beat detection from the 3.5 mm line input (you tap the downbeat)
- tAP — manual tap tempo

The active source is shown by a bar on the display (top = CDJ, middle = Tap, bottom = Mic, top + bottom = Line). See the **Sync Sources** section earlier in this manual for how each one works in practice.

**About CDJ source:** when set to Cdj, tapbox listens on the same Ethernet switch as your CDJ players and reads their beat timing automatically. The active CDJ's BPM is fed directly into the Ableton Link session — all your Link peers follow the CDJ without any tapping. A `C` indicator confirms the lock. tapbox follows the lowest player number (1 → 2 → 3 → 4); if that player stops for more than two seconds it drops to the next. While a CDJ is actively driving the tempo, the tap button is ignored — the CDJ is in control. If no CDJ is present, CDJ source behaves like manual tap tempo.

> CDJ sync requires Ethernet, on the same wired switch as the players. Nothing is installed on the CDJs — tapbox listens passively.

*Default: Aud*

---

### Audio Tuning

These settings apply to both audio sources — Mic and Line — whichever is active. The beat detector runs an FFT/mel-filterbank onset detector feeding a dynamic-programming beat tracker (`BTrack`) — see `BEAT_DETECTION.md` for the full pipeline. Your tap is always ground truth: the anchor tempo it sets never moves except by re-tapping. While `BTrack` is confident *and* its estimate is within your allowed BPM range of that anchor, the tempo follows it directly (so it responds to a pitch ride within a couple of beats); when confidence drops — silence, a breakdown, a beat-free passage — or the estimate strays outside the allowed range, the tempo holds its last good value until a beat clears every check again.

What counts as "confident enough," how loud a sound has to be to count as a beat at all, and how far you trust audio sensing to refine your tap all vary with your source, your room, and how much you want the detector doing — so four parameters on the **web config page**'s BPM tuning tab control them directly. (Line-in is electrically clean — no room noise — so it typically needs no Level floor at all; the floor mainly earns its keep on the microphone.)

- **Level floor** (dB, off by default): an absolute loudness floor. Without it, a completely silent room can still produce confident "beats" from something as quiet as keyboard typing, because the detector measures *relative* spectral change, not loudness. Watch the **Level** readout under the chart while music plays and while the room is quiet, then set the floor between the two — the readout is smoothed, so it settles rather than jumping around, but at low listening volumes the gap between "room" and "music" can be narrow; a louder room gives you more margin.
- **Lock confidence** (0.00–1.00, default 0.30): how confident `BTrack` must be for a beat to keep the sync **lock** alive and keep the beat grid phase-aligned. Lower this if the "LOCKED" state keeps dropping out on a quiet or reverberant mic signal.
- **Move confidence** (0.00–1.00, default 0.60): how confident `BTrack` must be before a beat is allowed to actually **change** the tempo. Higher is more cautious — a beat-free passage or ambient noise won't be able to nudge the tempo unless it clears this bar. Lower it if the tempo isn't updating even though the **Audio BPM** readout looks correct.
- **BPM range** (±1–20, default ±6): how far the mic's estimate may drift from your tapped tempo and still be trusted to move it. A reading further than this from your tap is ignored outright, no matter how confident — the tempo just holds. This is the main dial for how much you trust the mic versus your own tap; lower it to keep tapbox close to what you tapped, raise it if you want the mic doing more of the work. Re-tap any time to re-center the window on a new tempo.

Above the chart, a live readout shows three numbers — **Tap BPM** (what you last tapped), **Audio BPM** (the mic's current confidence-gated estimate), and **Link BPM** (the tempo actually driving the session) — plus the tracking state (idle / searching / locked). The chart itself plots the confidence trace against the lock/move lines (which move as you drag the sliders), with a tick for every beat — bright green if it cleared both the move-confidence bar and the BPM range and moved the tempo, dim grey if it only held the lock, red if a predicted beat was rejected by the level floor. A cluster of bright ticks with no music playing means Move confidence needs to come up, or Level floor needs to come up to reject the noise outright. Each slider applies immediately, live — there's no separate save step while tuning.

For a real-time view of tap/lock events without a serial cable — useful when testing tempo tracking against something like a DJ pitch fader — see the **Log** tab described above.

Below the chart, a rolling 10-second count shows **beats seen vs beats that moved the tempo**. Seen-but-didn't-move beats cleared the level floor and lock confidence but not move confidence (or fell outside the BPM range) — a high seen count with a low moved count usually means Move confidence or BPM range is set too tight for the current room, or the passage is genuinely ambiguous (a breakdown, sparse content).

The defaults work for typical four-on-the-floor material. For the full explanation of what each does and how to dial them in, see `BEAT_DETECTION.md`.

#### Why the tempo never flickers — and never drifts

There's a tension at the heart of every beat tracker. Audio analysis naturally jitters by a fraction of a BPM from beat to beat, so if you publish every reading, the tempo flickers across your whole rig — displays dance, devices chase noise. But if you smooth or ignore the small stuff, tiny errors should slowly *accumulate*: hold 126.3 while the music is really at 126.0 and the beat grid slides a little further off with every beat, until "beat 1" is audibly wrong.

tapbox resolves this with two mechanisms that cover for each other:

- **A steady tempo number.** Changes smaller than 0.4 BPM are ignored, so the BPM published to the Link session is rock solid — what you see on the display is what every peer sees, and none of them waste effort chasing estimation noise.
- **A self-correcting beat grid.** While locked, every detected beat gently pulls the beat grid a small step toward where the music actually is. Drift from a tiny tempo mismatch adds a *fixed* amount per beat, but the correction grows with the gap — so instead of sliding away, the grid settles at a constant offset of a few milliseconds, inaudible and bounded, forever.

The result is the best of both: a BPM number stable enough to trust on a big screen, and a beat grid that stays glued to the actual music indefinitely. Your downbeat is safe throughout — corrections always target the *nearest* beat, never re-guessing which beat is "1". That decision stays yours, made with your tap.

---

### Lan. — Network Mode

**What it does:** switches network addressing between automatic (DHCP), manual (static), and forced Access Point mode — applies to whichever interface, Ethernet or WiFi, is currently active.

- **Auto** — your router assigns tapbox an IP address automatically every time it boots.
- **Stat** — tapbox uses a fixed IP address, entered on the web config page (see below).
- **AP** — tapbox starts a wifi network called `tapbox` with IP address `192.168.4.1`. Useful if there's no other way to reach a browser, or if your normal WiFi network associates but won't actually pass traffic to the device (client isolation, captive portal) — this menu item lets you force your way back to a working config page without needing the network to cooperate first.

**When to use static:** if you send OSC commands from a DAW or control surface with a hard-coded destination address, a static IP ensures that address never changes between reboots.

When you confirm a change to this setting, tapbox displays `bOOt` and restarts automatically.

The static IP, subnet mask, and gateway themselves are entered on the **web config page** — see **Web Configuration Page** above — and only take effect when Lan. is set to **Stat**. Factory defaults: **192.168.1.200** / **255.255.255.0** / **192.168.1.1**.

*Default: Auto*

---

### vEr — Firmware Version

**What it does:** shows the firmware version currently running on your tapbox as `major.minor.patch` — for example, version 1.3.0 appears as `1.3.0`. Read-only.

---

### done — Exit Menu

Returns to normal mode immediately.

---

## System Functions

Both system functions are activated from **within the menu** by holding both buttons at the same time. Open the menu first (select short press), then hold both buttons. You do not need to power-cycle the device.

---

### OTA Firmware Update

Open the menu, then hold both the **tap button** and the **select button** for **3 seconds**. The display shows UPd.----. Release both buttons — the display changes to UPd Yes.

Press **select** to check for an update. tapbox contacts the server and compares the available version against what it's running. **Nothing reboots at this stage** — it just tells you what it found:

- **You're already up to date** → the display shows `UPd no` and returns to the menu. Nothing else happens.
- **The server can't be reached** (no internet route — e.g. a direct cable or AP-only connection) → the display shows `UPd Er` and returns to the menu.
- **A newer version is available** → the display shows `UP` followed by that version number, for example <code>UP&nbsp;1.15.0</code>. Now you decide: press **select** to install it, or **tap** (or just wait 6 seconds) to cancel. Nothing is downloaded or changed unless you accept.

If you accept, tapbox saves a pending-update flag to memory, erases OTA data if necessary to return to the factory slot, and reboots. On the next boot, as soon as it obtains a network connection (Ethernet or WiFi), it downloads and installs that firmware. The display shows `UPd.` followed by a progress percentage; when it reaches 100 it shows UPd. done and reboots into the new firmware. If the download itself fails partway, the display shows UPd. Er and tapbox continues to boot normally.

All settings are preserved across updates; only the firmware changes.

To cancel at any prompt: press **tap**, hold **select** for 1 second, or wait 6 seconds — tapbox returns to normal without scheduling anything.

---

### Factory Reset

Open the menu, then hold both the **tap button** and the **select button** for **8 seconds**. You will see UPd.---- at 3 seconds and then rSet Yes at 8 seconds. Release the buttons.

Press **select** to confirm. tapbox resets all settings to factory defaults — source to Mic, time signature to 4, brightness to 2, network to Auto, static address to 192.168.1.200 / 255.255.255.0 / 192.168.1.1 — clears any stored WiFi SSID and password, and reboots.

To cancel: press nothing (or press tap). The display returns to normal after 6 seconds without resetting anything.

After a factory reset the device boots into the original firmware from the factory partition. This guarantees the device can always be returned to working condition regardless of what happened during a previous OTA update.

---

## OSC Control

tapbox listens for OSC messages on **UDP port 8000**. Send your messages to the IP address shown on the display at boot.

| Command | What it does |
|---|---|
| `/tap` | Same as pressing the tap button |
| `/bpm <value>` | Set the tempo to a specific BPM |
| `/signature <value>` | Change the time signature (2 through 7) |
| `/nudge <ms>` | Shift the beat phase by `<ms>` milliseconds — positive nudges forward, negative nudges back. Omit the argument for a default 20ms nudge forward. |
| `/downbeat` | Reset the downbeat to this exact moment |

**A few ways to put this to use:**

- Map `/tap` to a pad on a MIDI controller via your DAW so the whole band can tap tempo from the stage.
- Send `/bpm 128` from an Ableton Live clip to snap the tempo to a specific value at the start of a track.
- Use `/downbeat` at the top of a new section to re-align the beat grid after a break.
- Assign `/nudge 40` and `/nudge -40` to fader buttons on a mixing desk for a decisive push/pull, or `/nudge 5` / `/nudge -5` for fine phase correction.

**Nudge notes:** a nudge shifts the shared Link timeline itself, so every connected app sees its beat grid move — it's not local to tapbox. With a **Mic or Line source locked**, the beat detector owns phase alignment: its phase-lock will pull the grid back onto the detected beats within a few beats, undoing the nudge. Nudge is therefore most useful with the CDJ and Tap sources; with Mic or Line, re-tap the downbeat instead.

---

## App Integration Guides

tapbox works with any Ableton Link or OSC-capable application. Setup guides for specific apps live in their own documents:

- **MadMapper** — see [`MADMAPPER.md`](MADMAPPER.md) for Ableton Link and OSC setup.

More app guides will be added over time.

---

## Tips and Tricks

**CDJ sync with Ableton Live:** plug tapbox into the same Ethernet switch as your CDJ players with CDJ sync turned On. The moment a CDJ starts playing, the `C` indicator lights up and every Ableton Live instance on the network locks to the CDJ tempo automatically — no tapping, no MIDI clock, no configuration on the CDJs.

**Tapping in from scratch:** for the most accurate reading, tap along with a steady source — a click track, a drum loop, or a song in headphones. Four clean taps is all you need to go live.

**The select button exits the menu.** Hold the select button for one second to back out or exit at any time, even mid-edit.

**Brightness at gigs:** set the brightness at soundcheck under the actual stage lighting, then save it. What looks comfortable in daylight may be too bright or too dim under stage wash.

**Using a static IP with OSC:** setting a static IP once means your OSC routing works every time without checking the display at each session.

**WiFi SSID is case-sensitive.** If tapbox cannot connect (reason 201 in the serial log), check that the SSID in the config page matches exactly — including capital letters and spaces.

**2.4 GHz only:** the ESP32 radio does not support 5 GHz WiFi. If your router broadcasts both bands under the same name, tapbox will find the 2.4 GHz one automatically. If it broadcasts them separately, enter the 2.4 GHz SSID.

**Keeping firmware up to date:** open the menu, hold both buttons for 3 seconds and release, then press select to check. tapbox tells you right away whether you're already current (`UPd no`), can't reach the server (`UPd Er`), or there's a newer version — in which case it shows the version and waits for you to accept before doing anything. If you accept, it installs on the next boot as soon as it has a network connection. Takes about 30 seconds. Settings are not affected.

---

## CDJ Simulator (Development Tool)

If you do not have a physical CDJ player available, `tools/cdj_sim_web.py` is a Python script that broadcasts genuine Pro DJ Link beat packets over UDP on port 50001. Run it on any computer on the same network as tapbox to test CDJ sync without real hardware.

```bash
python tools/cdj_sim_web.py [bpm] [player]
```

This opens a control page in your browser at **http://localhost:8080**. From there you can:

- Set BPM with the slider, the ±1 / ±0.1 nudge buttons, or keyboard arrows
- Select which player number (1–4) the simulator pretends to be
- Stop and start the beat stream to test the two-second CDJ timeout behaviour on tapbox
- Press **Downbeat** to force `beat 1` of the bar immediately — tapbox snaps its Ableton Link phase to match

The simulator requires Python 3 and no external packages.

---

## Troubleshooting

**No IP address scrolls across the display at boot.**  
tapbox could not connect to Ethernet within the boot timeout — 3 seconds if no cable is detected, or up to 15 seconds if a cable is present and using DHCP, to allow time for a lease or an AutoIP self-assigned address. Check the cable. If no cable is connected, tapbox starts WiFi — the display will scroll the IP once a connection is established, or `AP 192.168.4.1` if it falls back to access point mode.

**tapbox's IP address changed on its own a minute or two after boot.**  
This is the DHCP/AutoIP handoff, not a fault — see [DHCP, AutoIP fallback, and traps](#dhcp-autoip-fallback-and-traps). tapbox self-assigned a `169.254.x.x` address because no DHCP server answered right away, then a real lease arrived within the 2-minute grace window and took over — the display scrolled the new address when it happened. If you need the address to never move, set a static IP instead.

**tapbox shows dashes on the display after boot.**  
It is connected to the network but has not received any Link peers yet. This is normal — the display fills in once another Link device joins the session.

**WiFi connects but peers show 0.**  
Ensure the other device (e.g. MadMapper on a laptop) is on the same network. Link uses UDP multicast — some routers do not bridge multicast between WiFi and Ethernet. If your PC is on Ethernet and tapbox is on WiFi, try connecting tapbox via Ethernet instead.

**tapbox cannot find my WiFi network (or connects then immediately disconnects).**  
Check that you entered the SSID exactly as it appears on your phone — SSIDs are case-sensitive. Also confirm the network is 2.4 GHz; the ESP32 cannot connect to 5 GHz networks. If credentials fail, tapbox falls back to AP mode automatically — connect to the **tapbox** network using its PIN and open **http://192.168.4.1** to correct them.

**My OSC messages are not reaching tapbox.**  
Confirm the IP address on the display at next boot and update your OSC destination. If using a static IP, verify the address, subnet, and gateway are correct.

**I set a static IP and now tapbox is unreachable.**  
Use the factory reset (open the menu, hold both buttons 8 s, then confirm with select) to return to Auto DHCP. The display will show the assigned address at the next boot.

**The display is very dim after a restart.**
tapbox detected a brownout (power dip) during the previous session and has automatically set brightness to level 1 to protect against a repeat. You can raise it in the menu under Led and save. If it keeps happening, check your power supply.

**The tempo drifts slightly after many taps.**  
tapbox calculates BPM as an average across all taps in the session. Small variations in tap timing do shift the average, though the effect becomes smaller with each additional tap. For a locked-in tempo, tap steadily for 8 or more beats, then stop and let Link hold the tempo.

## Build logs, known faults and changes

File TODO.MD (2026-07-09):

Ideas (parked):
- BPM range gate (g_micRange, BEAT_DETECTION.md §8/§13) is currently binary
  in/out — a candidate either clears g_micConfMove AND is within range, or
  it's HOLD. Discussed 2026-07-09: replace the flat move-confidence
  threshold with a ramp that requires higher confidence the closer a
  candidate gets to the range boundary (starting at the existing
  g_micConfMove value right at the anchor, rising to unreachable exactly at
  the edge) — would unify the range and confidence checks into one
  mechanism instead of two ANDed conditions, and "outside range" would fall
  out naturally rather than needing a separate case. Explicitly deferred in
  favor of shipping the binary version first ("let's start with this where
  the range is binary for now") — revisit once the binary version has been
  used for a while.
- ws_push_task (browser telemetry) currently pushes at 20Hz, matching
  mic_task's poll rate purely by coincidence — the two are independent
  loops. mic_task's 20Hz cadence must stay (real tempo-path latency: how
  fast follow/hold reacts to a confident beat). ws_push_task is purely
  cosmetic (chart/readouts) and could likely drop to ~10Hz unnoticed —
  beat ticks are already stamped with their own precise timestamp (age
  field), and confidence/BPM don't change faster than perceptible anyway.
  Would roughly halve WS traffic + httpd_queue_work/malloc churn while a
  browser tab is open. Needs the chart's hardcoded frac divisor (currently
  50ms, in mDraw's rAF loop) updated to match the new interval so the
  scroll interpolation doesn't overshoot between packets.
- A real-time AI audio feature extractor is being developed externally and
  may replace the current front-end (FFT/mel/SuperFlux/BTrack); everything
  downstream (octave fold, snap/clamp, phase-lock, tuning UI) consumes onset
  timestamps and would carry over unchanged.
- CPU headroom is currently unmeasured — no core pinning (plain xTaskCreate,
  not xTaskCreatePinnedToCore) and no FreeRTOS runtime-stats config
  (CONFIG_FREERTOS_GENERATE_RUN_TIME_STATS not set), so there's nothing to
  read off today, unlike flash/RAM which the build reports automatically.
  If worth knowing for real: enable runtime stats and print core idle time
  over serial, or wrap the mic_task hot path (FFT→Mel→SuperFlux→BTrack) in
  esp_timer to check per-hop cost against the 62.5Hz (16ms) budget. Case is
  currently screwed shut — not urgent, just want to check at some point.
- Move-tier false negative: confidence can sit just under g_micConfMove while
  the folded candidate is rock solid (observed on real hardware, known-correct
  reading that never moved the tempo). Add a consistency fallback at the move
  check in mic_task() (~main.cpp:2235): track consecutive lock-tier beats
  whose folded `cand` stays within a tight band (e.g. ±0.3 BPM) of each other,
  accumulating a growing count rather than a one-shot pass/fail — a run of
  otherwise-quality beats should eventually overcome a marginal confidence
  shortfall on its own, so let the count satisfy the move gate once it
  crosses a threshold (e.g. 4, matching the existing lock-count convention)
  even when confidence alone doesn't. This is an OR alternative to the
  confidence check, not an extra required condition — it only makes moves
  *more* permissive for cases already known to be trustworthy, so it
  shouldn't reintroduce the old accept-window's lag (which instead made
  every move harder to pass). Reset the accumulating counter wherever
  `consec` already resets (mode change, lock loss), and any time `cand`
  jumps outside the tight band (a real break in consistency, not just a
  low-confidence read).
  Also gate this fallback to a conservative BPM range — the algorithm has
  a known tendency to hang at the ~160 BPM alias ceiling during quiet
  passages (tempo_estimator.h's ~85-160 BPM reliable range; BEAT_DETECTION.md
  §6 on aliasing above ~164 BPM). A quiet passage is exactly when a wrong
  but stable alias could rack up enough consecutive "consistent" beats to
  trip this fallback, so don't let the counter alone override confidence
  when `cand` is sitting near that high ceiling — only apply it comfortably
  away from the edge, some margin below ~160 BPM.
  **Reconsider before implementing (2026-07-09):** the move check is no
  longer gated by a ±20% clamp — it's now `g_micRange` (default ±6 BPM,
  user-tunable, see BEAT_DETECTION.md §8/§13). A default-config alias would
  have to land within 6 BPM of the tapped anchor to even be a candidate,
  which is a much narrower coincidence than the old ±20% window, so the
  aliasing-ceiling risk this fallback guards against is smaller than when
  this idea was written. More importantly, this session's redesign pulled
  deliberately *toward* the tap being sole ground truth and audio sensing
  doing less unsupervised work, not more — a fallback that makes moves more
  permissive cuts against that direction. Don't implement without
  re-discussing whether it's still wanted.

Nice to have (parked):
- WiFi AP alongside Ethernet: currently Ethernet connecting calls
  wifi_stop() unconditionally, so WiFi is fully off whenever Ethernet is
  active. Ethernet (LAN8720 PHY) and WiFi are separate hardware though —
  no radio conflict like AP+STA sharing the WiFi radio — so it's feasible
  to keep an AP running purely for config-page access from a phone/laptop
  while Ethernet still carries Link as normal. Would need a decision on
  default posture (always-on AP-over-Ethernet vs. a menu toggle — leaning
  toggle, since it's a real change to how the device presents itself on
  networks) and costs a bit more power draw.

Cosmetic (parked):
- Do we want slider changes to NOT hit NVS flash on every drag? Currently
  /apply saves to NVS each time (flash wear, minor).
- Save Tuning button should return to the correct tab after posting.

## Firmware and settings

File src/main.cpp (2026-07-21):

#include <stdio.h>
#include <cmath>
#include <string.h>
#include <cstdarg>
#include "freertos/FreeRTOS.h"
#include "freertos/task.h"
#include "nvs_flash.h"
#include "nvs.h"
#include "esp_event.h"
#include "esp_netif.h"
#include "esp_system.h"
#include "esp_timer.h"
#include "esp_log.h"
#include "driver/gpio.h"
#include "driver/ledc.h"
#include "driver/i2s_std.h"
#include "esp_https_ota.h"
#include "esp_http_client.h"
#include "esp_crt_bundle.h"
#include "esp_ota_ops.h"
#include "esp_partition.h"
#include "abl_link.h"
#include "tap_tempo.h"
#include "ethernet_config.h"
#include "max7219.h"
#include "lwip/sockets.h"
#include "esp_wifi.h"
#include "esp_http_server.h"
#include "esp_mac.h"

#include "dsp/ring_buffer.h"
#include "dsp/fft_processor.h"
#include "dsp/mel_filterbank.h"
#include "dsp/superflux_onset.h"
#include "dsp/btrack.h"

// ── Pin assignments ────────────────────────────────────────────────────────────
#define PIN_TAP_BUTTON  GPIO_NUM_35  // input-only — needs external 10k pullup to 3V3
#define PIN_SELECT      GPIO_NUM_39  // input-only — needs external 10k pullup to 3V3
#define PIN_DISP_CLK    GPIO_NUM_14
#define PIN_DISP_DIN    GPIO_NUM_2
#define PIN_DISP_LOAD   GPIO_NUM_15
#define PIN_I2S_BCLK    GPIO_NUM_4   // INMP441 SCK
#define PIN_I2S_WS      GPIO_NUM_12  // INMP441 WS  (strapping pin; eFuse-locked on WT32-ETH01)
#define PIN_I2S_DIN     GPIO_NUM_36  // INMP441 SD  (was battery ADC)
#define MIC_SAMPLE_RATE 32000
#define PIN_LINE_SCKI   GPIO_NUM_5   // PCM1808 SCKI — LEDC 8MHz (see PCM1808_PLAN.md)
#define PIN_LINE_BCK    GPIO_NUM_17  // PCM1808 BCK  (2MHz, PCM1808-generated → input)
#define PIN_LINE_WS     GPIO_NUM_32  // PCM1808 LRC  (31.25kHz, PCM1808-generated → input)
#define PIN_LINE_DIN    GPIO_NUM_33  // PCM1808 OUT  (audio data → input)
#define LINE_SAMPLE_RATE 31250       // 8MHz SCKI ÷ 256fs

// ── Constants ──────────────────────────────────────────────────────────────────
#define DEBOUNCE_MS     20  // lockout after an accepted edge; Sanwa OBSF release chatter exceeds the old 5ms
#define DISPLAY_MS      50
#define MENU_TIMEOUT_MS 6000
#define LONG_PRESS_MS   2000
#define SELECT_LONG_MS  1000
#define OSC_PORT        8000
#define OTA_URL         "https://dinther.github.io/tapbox/firmware.bin"
#define MANIFEST_URL    "https://dinther.github.io/tapbox/manifest.json"

// ── 7-segment characters (D6=A … D0=G) ────────────────────────────────────────
static constexpr uint8_t CH_a = 0x7D;
static constexpr uint8_t CH_A = 0x77;
static constexpr uint8_t CH_b = 0x1F;
static constexpr uint8_t CH_B = 0x7F;
static constexpr uint8_t CH_d = 0x3D;
static constexpr uint8_t CH_e = 0x6F;
static constexpr uint8_t CH_h = 0x17;
static constexpr uint8_t CH_I = 0x30;
static constexpr uint8_t CH_i = 0x10;  // lowercase i: segment C only
static constexpr uint8_t CH_L = 0x0E;
static constexpr uint8_t CH_o = 0x1D;
static constexpr uint8_t CH_n = 0x15;
static constexpr uint8_t CH_P = 0x67;
static constexpr uint8_t CH_r = 0x05;
static constexpr uint8_t CH_S = 0x5B;
static constexpr uint8_t CH_t = 0x0F;
static constexpr uint8_t CH_u = 0x1C;
static constexpr uint8_t CH_C    = 0x4E;  // segments A,D,E,F
static constexpr uint8_t CH_F    = 0x47;  // segments A,E,F,G
static constexpr uint8_t CH_J    = 0x38;  // segments B,C,D
static constexpr uint8_t CH_y    = 0x3B;  // segments B,C,D,F,G

// Mode indicator bars (single horizontal segment, see project memory for encoding)
static constexpr uint8_t BAR_TOP = 0x40;  // segment A  → CDJ mode
static constexpr uint8_t BAR_MID = 0x01;  // segment G  → Manual mode
static constexpr uint8_t BAR_BOT = 0x08;  // segment D  → Audio mode

// ── Firmware version ───────────────────────────────────────────────────────────
#define FW_MAJOR 1
#define FW_MINOR 14
#define FW_PATCH 3

// ── Menu option tables ─────────────────────────────────────────────────────────
static const double kSignatures[] = { 2.0, 3.0, 4.0, 5.0, 6.0, 7.0 };
static const int    kSigCount     = 6;

#define DEFAULT_NUDGE_MS 20  // used by OSC /nudge when no argument is given

static const int    kBritLevels[] = { 1, 5, 10, 15 };  // user levels 1-4 → MAX7219 intensity
static const int    kBritCount    = 4;

// ── Sync source (mutually exclusive) ────────────────────────────────────────────
// Values are NVS-persisted — append only, never renumber (a stored 2 must stay
// tap mode across upgrades). MODE_LINE (PCM1808 line-in) appended 2026-07-14.
enum SyncMode { MODE_CDJ = 0, MODE_MIC = 1, MODE_MANUAL = 2, MODE_LINE = 3 };
// Mic and Line-in are both "audio" sources: same tap-anchor/range-gate/lock
// behavior, different capture hardware and sample rate.
static inline bool mode_is_audio(int m) { return m == MODE_MIC || m == MODE_LINE; }

// ── Persistent settings ────────────────────────────────────────────────────────
static int g_sigIdx   = 2;             // kSignatures[2] = 4/4
static int g_brit     = 1;             // brightness level index 0–3 (→ kBritLevels)
static int g_net      = 0;             // 0=DHCP, 1=static
static int g_mode     = MODE_MIC;    // 0=CDJ, 1=Mic, 2=Tap (manual), 3=Line-in
// Mic tuning knobs — the real tempo path's four gates (see mic_task),
// exposed as sliders because none are derivable analytically.
static int g_micFloor    = -100;       // absolute level floor, dB of mean FFT power (-100 = off, up to -10)
static int g_micConfSil  = 30;         // BTrack confidence ×100 to keep lock/PLL fed (0–100)
static int g_micConfMove = 60;         // BTrack confidence ×100 required to MOVE the tempo (0–100)
static int g_micRange    = 6;          // ±BPM window around the tap anchor that audio sensing may move tempo within (1–20)
static int g_ip[4]    = {192, 168,   1, 200};
static int g_sn[4]    = {255, 255, 255,   0};
static int g_gt[4]    = {192, 168,   1,   1};
static char g_wifi_ssid[64] = {};
static char g_wifi_pass[64] = {};

// ── RTC memory — survives esp_restart() but not power-on; used to restore
//    settings if NVS is erased on the boot following an OTA update. ────────────
struct RtcSettings {
    uint32_t magic;
    int sigIdx, brit, net, mode;
    int micFloor, micConfSil, micConfMove, micRange;
    int ip[4], sn[4], gt[4];
    char wifi_ssid[64], wifi_pass[64];
};
// Bumped whenever RtcSettings' layout changes — a stale layout from the
// pre-OTA firmware must not be restored field-shifted into NVS.
static constexpr uint32_t RTC_MAGIC = 0xCAFEB011;
RTC_DATA_ATTR static RtcSettings s_rtc;

// ── Core globals ───────────────────────────────────────────────────────────────
static TapTempo                  tapTempo;
static MAX7219Display            display(PIN_DISP_CLK, PIN_DISP_DIN, PIN_DISP_LOAD);

static abl_link               s_link;
static abl_link_session_state s_session;
static bool   linkEnabled = false;
static double linkQuantum = 4.0;

// ── Button state ───────────────────────────────────────────────────────────────
struct BtnCtx {
    int      last         = 1;
    uint32_t last_db      = 0;
    uint32_t pressed_at   = 0;
    bool     long_fired   = false;
    uint32_t auto_incr_at = 0;  // tap button only
};
static BtnCtx s_tap_ctx;
static BtnCtx s_sel_ctx;

enum BothHeldState { BH_IDLE, BH_HELD, BH_OTA, BH_RESET };
static BothHeldState s_bh_state = BH_IDLE;
static uint32_t      s_bh_since = 0;

static volatile bool g_cdj_active = false;  // set by cdj_task; read by display + input

// ── Mic / beat-detection runtime state ──────────────────────────────────────────
static i2s_chan_handle_t s_i2s_rx     = nullptr;
static i2s_chan_handle_t s_i2s_line   = nullptr;  // PCM1808 line-in (slave RX, I2S1)
static volatile double   g_mic_bpm    = 0.0;    // last raw detected BPM (display hint)
static volatile bool     g_mic_locked = false;  // mic has a stable tracked BPM
static volatile bool     g_mic_armed  = false;  // a tap has anchored the tracker
static volatile double   g_mic_tracked = 0.0;   // adaptive anchor / applied BPM
static volatile double   g_mic_tapAnchor = 0.0; // last tap-set tempo (clamp reference)

// Live telemetry for the web page's audio-tuning chart — written by mic_task's
// 20Hz poll, read every 50ms by the WS push task. Beat is latched between
// pushes so a push landing mid-cycle can't miss one.
static volatile float  g_tele_level     = -120.f; // ~800ms-smoothed FFT power, dB (levelEmaDb) — page shows it for the floor slider
static volatile uint8_t g_tele_onset    = 0;  // latched beat since last push (0=none 1=lock-tier 2=move-tier); reset by push task
static volatile float   g_tele_conf     = 0.f;    // BTrack confidence at last poll — chart's confidence trace
static volatile uint32_t g_tele_onsetMs = 0;      // beat hop's time (ms) — page places the tick sub-sample
// Running totals (wrap-safe on the client): beats seen (floor + lock tier),
// and beats that cleared the move tier and could move the tempo.
static volatile uint32_t g_tele_det = 0;
static volatile uint32_t g_tele_acc = 0;

static bool g_manual_locked = false;  // true after first 4-tap session in Manual mode

static bool g_wifi_enabled = false;
static bool g_wifi_as_ap   = false;
static bool g_wifi_got_ip  = false;
static bool g_eth_got_ip   = false;
static bool g_eth_lost     = false;
static bool g_ap_started   = false;
static char g_wifi_ip_str[16] = {};

// AP/web-config PIN — see compute_security_pin() for how this is derived.
// Declared here (rather than down by the WiFi/HTTP code) so the boot/reconnect
// scroll splash can always append it, in every network mode.
static char g_ap_pin[9] = "00000000";

// ── Non-blocking one-shot scroll (boot/reconnect IP splash) ───────────────────
#define PIN_HOLD_MS 6000  // how long the scroll pauses once the PIN fills the display
static uint8_t  s_scroll_buf[48]    = {};
static int      s_scroll_len        = 0;
static int      s_scroll_offset     = -7;
static uint32_t s_scroll_step_ms    = 0;
static bool     s_scroll_active     = false;
static bool     s_scroll_holding    = false;  // paused with the PIN fully shown
static uint32_t s_scroll_hold_start = 0;

// ── Menu state ─────────────────────────────────────────────────────────────────
// MODE_OTA_CONFIRM        — "check for an update?" (select runs the check)
// MODE_OTA_INSTALL_CONFIRM — a newer version was found; its number is shown and
//                            the user decides whether to install (select) or not
enum AppMode { MODE_NORMAL, MODE_MENU_NAV, MODE_MENU_EDIT, MODE_MENU_CONFIRM,
               MODE_OTA_CONFIRM, MODE_OTA_INSTALL_CONFIRM };
static AppMode  appMode       = MODE_NORMAL;
static uint32_t menuEnteredAt = 0;

// Version found by the OTA check, shown on the MODE_OTA_INSTALL_CONFIRM screen.
static int g_otaAvailMajor = 0, g_otaAvailMinor = 0, g_otaAvailPatch = 0;

// Mic tuning (uind/SLEu/thr/gAte) and static-IP octets (IP/Sub./Hub.) are
// configured on the web page only — see http_get_root(). The on-device menu
// only carries settings usable without a browser at hand.
enum MenuIdx {
    MENU_SIG = 0, MENU_BRIT, MENU_MODE,
    MENU_NET, MENU_CURIP,
    MENU_RESET, MENU_VER, MENU_DONE,
    MENU_COUNT  // 8
};
static int menuItem    = 0;
static int menuEditVal = 0;

// Snapshot of network config taken on menu entry; compared on exit so we
// reboot exactly once if the Lan. mode actually changed.
static int g_net_snap = 0;

// ── Time helpers ───────────────────────────────────────────────────────────────
static inline uint32_t now_ms() { return (uint32_t)(esp_timer_get_time() / 1000ULL); }
static inline uint64_t now_us() { return (uint64_t)esp_timer_get_time(); }

static void show_boot_reboot();          // forward declaration
static void nvs_save_wifi();             // forward declaration
static void nvs_save_ota_pending(bool);  // forward declaration
static void rtc_save_settings();         // forward declaration
static void wifi_init();                 // forward declaration
static void wifi_stop();                 // forward declaration
static void do_tap();                    // forward declaration

static void eth_lost_cb(void *, esp_event_base_t, int32_t, void *) {
    g_eth_lost = true;
}
static void eth_got_ip_cb(void *, esp_event_base_t, int32_t, void *) {
    g_eth_got_ip = true;
}
static void eth_connected_cb(void *, esp_event_base_t, int32_t, void *) {
    // For static IP, ethernet_config.h sets ethConnected in this same event
    // (its handler registered first). If true here, this is a static IP reconnect.
    if (ethConnected) g_eth_got_ip = true;
}

// ── Settings ───────────────────────────────────────────────────────────────────

static void apply_settings() {
    linkQuantum = kSignatures[g_sigIdx];
    display.setIntensity(kBritLevels[g_brit]);
}

static void nvs_load_settings() {
    nvs_handle_t h;
    if (nvs_open("settings", NVS_READONLY, &h) != ESP_OK) {
        apply_settings();
        return;
    }
    int32_t v;
    if (nvs_get_i32(h, "sig",  &v) == ESP_OK && v >= 0 && v < kSigCount)   g_sigIdx   = (int)v;
    if (nvs_get_i32(h, "brit", &v) == ESP_OK && v >= 0 && v <= 3)          g_brit     = (int)v;
    if (nvs_get_i32(h, "mode", &v) == ESP_OK && v >= 0 && v <= 3)          g_mode     = (int)v;
    if (nvs_get_i32(h, "mfloor",&v)== ESP_OK && v >= -100 && v <= -10)     g_micFloor = (int)v;
    if (nvs_get_i32(h, "mcsil",&v) == ESP_OK && v >= 0 && v <= 100)        g_micConfSil  = (int)v;
    if (nvs_get_i32(h, "mcmove",&v)== ESP_OK && v >= 0 && v <= 100)        g_micConfMove = (int)v;
    if (nvs_get_i32(h, "mrange",&v)== ESP_OK && v >= 1 && v <= 20)         g_micRange = (int)v;
    if (nvs_get_i32(h, "net",  &v) == ESP_OK && v >= 0 && v <= 2)          g_net      = (int)v;
    if (nvs_get_i32(h, "ip0",  &v) == ESP_OK && v >= 0 && v <= 255)        g_ip[0]    = (int)v;
    if (nvs_get_i32(h, "ip1",  &v) == ESP_OK && v >= 0 && v <= 255)        g_ip[1]    = (int)v;
    if (nvs_get_i32(h, "ip2",  &v) == ESP_OK && v >= 0 && v <= 255)        g_ip[2]    = (int)v;
    if (nvs_get_i32(h, "ip3",  &v) == ESP_OK && v >= 0 && v <= 255)        g_ip[3]    = (int)v;
    if (nvs_get_i32(h, "sn0",  &v) == ESP_OK && v >= 0 && v <= 255)        g_sn[0]    = (int)v;
    if (nvs_get_i32(h, "sn1",  &v) == ESP_OK && v >= 0 && v <= 255)        g_sn[1]    = (int)v;
    if (nvs_get_i32(h, "sn2",  &v) == ESP_OK && v >= 0 && v <= 255)        g_sn[2]    = (int)v;
    if (nvs_get_i32(h, "sn3",  &v) == ESP_OK && v >= 0 && v <= 255)        g_sn[3]    = (int)v;
    if (nvs_get_i32(h, "gt0",  &v) == ESP_OK && v >= 0 && v <= 255)        g_gt[0]    = (int)v;
    if (nvs_get_i32(h, "gt1",  &v) == ESP_OK && v >= 0 && v <= 255)        g_gt[1]    = (int)v;
    if (nvs_get_i32(h, "gt2",  &v) == ESP_OK && v >= 0 && v <= 255)        g_gt[2]    = (int)v;
    if (nvs_get_i32(h, "gt3",  &v) == ESP_OK && v >= 0 && v <= 255)        g_gt[3]    = (int)v;
    // WiFi credentials loaded here — avoids a second NVS open in wifi_init()
    size_t len;
    len = sizeof(g_wifi_ssid); nvs_get_str(h, "wifi_ssid", g_wifi_ssid, &len);
    len = sizeof(g_wifi_pass); nvs_get_str(h, "wifi_pass", g_wifi_pass, &len);
    nvs_close(h);
    apply_settings();
}
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
extern "C" void app_main(void) {
    esp_err_t ret = nvs_flash_init();
    if (ret == ESP_ERR_NVS_NO_FREE_PAGES || ret == ESP_ERR_NVS_NEW_VERSION_FOUND) {
        nvs_flash_erase();
        nvs_flash_init();
    }
    rtc_restore_to_nvs_if_valid();

    esp_event_loop_create_default();
    esp_netif_init();

    compute_security_pin();

    init_gpio();
    init_i2s_mic();
    line_clock_start();  // PCM1808 SCKI — Phase 1, see PCM1808_PLAN.md
    init_i2s_line();     // PCM1808 slave RX — Phase 3
    display.init();

    // Earliest possible "alive" indicator: light every segment the moment the
    // display is up, so the operator can see the board booted and the display
    // works — well before the (slow) Ethernet link and IP splash appear. This
    // persists through the Ethernet wait until the splash/normal view replaces it.
    {
        display.setIntensity(8);
        uint8_t boot[8];
        for (int i = 0; i < 8; i++) boot[i] = 0xFF;  // all segments + DP
        display.setSegments(boot);
    }

    nvs_load_settings();  // loads all settings including WiFi credentials

    if (esp_reset_reason() == ESP_RST_BROWNOUT) {
        g_brit = 0;
        display.setIntensity(kBritLevels[0]);
        printf("Brownout detected — brightness forced to level 1\n");
    }

    // Check for OTA pending flag (set by holding both buttons in normal mode)
    bool ota_pending = false;
    {
        nvs_handle_t nvs_h;
        if (nvs_open("settings", NVS_READONLY, &nvs_h) == ESP_OK) {
            int32_t v = 0;
            if (nvs_get_i32(nvs_h, "ota_pend", &v) == ESP_OK) ota_pending = (v == 1);
            nvs_close(nvs_h);
        }
    }
    if (ota_pending) nvs_save_ota_pending(false);  // clear flag immediately

    if (g_net != 2) {
        initEthernet(g_net, g_ip, g_sn, g_gt);

        // Static IP only needs link-up (~2 s). DHCP needs address assignment:
        // a lease normally lands within ~5 s, but with no DHCP server on the
        // wire (direct cable to a Denon player or laptop) lwIP auto-IP
        // self-assigns a 169.254.x.x address, which takes ~10 s. Wait that
        // long only while a cable is present — no link after 3 s means no
        // cable, so fall through to WiFi quickly.
        printf("Waiting for Ethernet");
        uint32_t start = now_ms();
        while (!ethConnected) {
            uint32_t limit = (g_net == 0 && ethLinkUp) ? 15000 : 3000;
            if (now_ms() - start >= limit) break;
            vTaskDelay(pdMS_TO_TICKS(250));
            printf(".");
            fflush(stdout);
        }
        printf("\n");
    }

    if (!ethConnected) wifi_init();

    // Register after the boot wait so the initial IP event doesn't trigger switching
    esp_event_handler_register(ETH_EVENT, ETHERNET_EVENT_DISCONNECTED, eth_lost_cb,     nullptr);
    esp_event_handler_register(ETH_EVENT, ETHERNET_EVENT_CONNECTED,    eth_connected_cb, nullptr);
    esp_event_handler_register(IP_EVENT,  IP_EVENT_ETH_GOT_IP,         eth_got_ip_cb,   nullptr);

    s_link    = abl_link_create(120.0);
    s_session = abl_link_create_session_state();
    tapTempo.setBpm(120.0);

    if (ethConnected) {
        printf("IP: %s\n", ethIPStr);
        abl_link_enable(s_link, true);
        linkEnabled = true;
        abl_link_capture_app_session_state(s_link, s_session);
        abl_link_set_tempo(s_session, 120.0, now_us());
        abl_link_commit_app_session_state(s_link, s_session);
        printf("Link live at 120.0 BPM\n");
        http_server_start();
        if (ota_pending) { ota_pending = false; perform_ota(); }
        else { static const uint8_t kEth[] = { CH_e, CH_t, CH_h }; start_scroll_splash(kEth, 3, ethIPStr); }
    } else {
        printf("No Ethernet — waiting for WiFi\n");
    }

    // Confirm to the bootloader that this firmware booted successfully.
    // If the device was just OTA-updated, this prevents rollback on next boot.
    esp_ota_mark_app_valid_cancel_rollback();

    xTaskCreate(osc_task, "osc", 4096, nullptr, 5, nullptr);
    printf("OSC listening on port %d\n", OSC_PORT);
    xTaskCreate(cdj_task, "cdj", 4096, nullptr, 5, nullptr);
    printf("CDJ listener on port %d\n", CDJ_PORT);
    xTaskCreate(mic_task, "mic", 8192, nullptr, 5, nullptr);
    printf("Mic beat detector started\n");
    xTaskCreate(ws_push_task, "ws_push", 3072, nullptr, 4, nullptr);

    while (true) {
        handle_system_buttons();
        handle_button();
        handle_select();
        check_menu_timeout();
        if (g_sta_failed) {
            g_sta_failed = false;
            printf("WiFi STA failed — falling back to AP\n");
            wifi_stop();
            wifi_start_ap();
        }
        eth_check_autoip_grace();
        if (g_eth_lost) {
            g_eth_lost = false;
            printf("Ethernet lost — starting WiFi\n");
            wifi_init();
        }
        if (g_wifi_got_ip) {
            g_wifi_got_ip = false;
            abl_link_enable(s_link, false);
            vTaskDelay(pdMS_TO_TICKS(100));
            abl_link_enable(s_link, true);
            linkEnabled = true;
            printf("Link re-enabled on WiFi interface\n");
            if (ota_pending) { ota_pending = false; perform_ota(); }
            else { static const uint8_t kSta[] = { CH_S, CH_t, CH_A }; start_scroll_splash(kSta, 3, g_wifi_ip_str); }
        }
        if (g_eth_got_ip) {
            g_eth_got_ip = false;
            if (g_wifi_enabled) {
                printf("Ethernet back — stopping WiFi\n");
                wifi_stop();
            }
            abl_link_enable(s_link, false);
            vTaskDelay(pdMS_TO_TICKS(100));
            abl_link_enable(s_link, true);
            linkEnabled = true;
            http_server_start();
            printf("Link re-enabled on Ethernet interface\n");
            if (ota_pending) { ota_pending = false; perform_ota(); }
            else { static const uint8_t kEth[] = { CH_e, CH_t, CH_h }; start_scroll_splash(kEth, 3, ethIPStr); }
        }
        if (g_ap_started) {
            g_ap_started = false;
            abl_link_enable(s_link, false);
            vTaskDelay(pdMS_TO_TICKS(100));
            abl_link_enable(s_link, true);
            linkEnabled = true;
            static const uint8_t kAp[] = { CH_A, CH_P };
            start_scroll_splash(kAp, 2, "192.168.4.1");
        }
        update_display();
        print_status();
        vTaskDelay(pdMS_TO_TICKS(1));
    }
}

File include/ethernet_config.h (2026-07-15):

#pragma once
#include <string.h>
#include <stdio.h>
#include "esp_eth.h"
#include "esp_event.h"
#include "esp_netif.h"
#include "esp_log.h"
#include "esp_timer.h"
#include "driver/gpio.h"

static const char *ETH_TAG = "eth";

static bool ethConnected = false;   // link up AND usable IP (DHCP, auto-IP, or static)
static bool ethLinkUp    = false;   // physical link only — cable plugged into a live port
static char ethIPStr[16]  = "0.0.0.0";

static esp_netif_t *s_eth_netif  = nullptr;
static bool         s_use_static = false;

// Once AutoIP (169.254.x.x) claims an address because DHCP hasn't answered
// yet, DHCP keeps quietly retrying in the background and can override the
// address later — fine during setup, dangerous mid-show if a tech has
// already configured against the AutoIP address. Give DHCP a grace window
// to still win the race, then stop it so the address can't change again
// until the cable is re-seated.
static bool          s_eth_autoip_pending  = false;
static int64_t       s_eth_autoip_since_us = 0;
static const int64_t ETH_AUTOIP_GRACE_US   = 120LL * 1000000LL;  // 2 minutes

static void on_eth_event(void *, esp_event_base_t, int32_t id, void *) {
    switch (id) {
        case ETHERNET_EVENT_START:
            esp_netif_set_hostname(s_eth_netif, "tapbox");
            break;
        case ETHERNET_EVENT_CONNECTED:
            ethLinkUp = true;
            s_eth_autoip_pending = false;
            if (s_use_static) {
                // With static IP there is no GOT_IP event; mark connected here
                // and populate ethIPStr from the netif's configured address.
                esp_netif_ip_info_t info;
                if (esp_netif_get_ip_info(s_eth_netif, &info) == ESP_OK)
                    esp_ip4addr_ntoa(&info.ip, ethIPStr, sizeof(ethIPStr));
                ethConnected = true;
            } else {
                // Re-seating the cable should restart the DHCP/AutoIP race
                // fresh, even if a previous grace-window timeout stopped DHCP.
                esp_netif_dhcpc_start(s_eth_netif);
            }
            break;
        case ETHERNET_EVENT_DISCONNECTED:
        case ETHERNET_EVENT_STOP:
            ethLinkUp    = false;
            ethConnected = false;
            s_eth_autoip_pending = false;
            break;
        default:
            break;
    }
}

static void on_got_ip(void *, esp_event_base_t, int32_t, void *data) {
    // Only used in DHCP mode; static mode sets ethConnected in on_eth_event.
    if (s_use_static) return;
    ip_event_got_ip_t *event = (ip_event_got_ip_t *)data;
    ethConnected = true;
    esp_ip4addr_ntoa(&event->ip_info.ip, ethIPStr, sizeof(ethIPStr));
    ESP_LOGI(ETH_TAG, "IP: %s", ethIPStr);

    if (strncmp(ethIPStr, "169.254.", 8) == 0) {
        if (!s_eth_autoip_pending) {
            s_eth_autoip_pending  = true;
            s_eth_autoip_since_us = esp_timer_get_time();
        }
    } else {
        s_eth_autoip_pending = false;  // a real DHCP lease won the race
    }
}

// Call periodically from the main loop. Once an AutoIP address has held for
// ETH_AUTOIP_GRACE_US with no DHCP lease arriving, stop the DHCP client so
// the address is stable for the rest of the show — only a cable re-seat
// (ETHERNET_EVENT_CONNECTED) restarts the race.
static void eth_check_autoip_grace() {
    if (!s_eth_autoip_pending) return;
    if (esp_timer_get_time() - s_eth_autoip_since_us < ETH_AUTOIP_GRACE_US) return;
    s_eth_autoip_pending = false;
    esp_netif_dhcpc_stop(s_eth_netif);
    ESP_LOGI(ETH_TAG, "AutoIP address held with no DHCP reply — stopped retrying");
}
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

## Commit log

2026-06-19 Initial commit — ESP32 tap-tempo Ableton Link box
    ESP-IDF project for WT32-ETH01. Implements 4-tap BPM detection,
    Ableton Link sync over Ethernet, TM1637 display, beat-flash LED,
    nudge buttons, and rotary encoder. Boots at 120 BPM on Link.
    Pin assignments verified against WT32-ETH01 v1.4 board (encoder
    moved off RMII pins GPIO25/26/27). Network BPM is display-only
    and never written back to local state to prevent feedback loops.
    [ethernet_config.h, main.cpp]
2026-06-20 Replace TM1637 with MAX7219 8-digit display, add OSC server, time signature menu
    - Swap TM1637 4-digit display for MAX7219 8-digit (CLK=IO14, DIN=IO2, LOAD=IO15)
    - Display layout: BPM.d | beat-in-bar | peer-count, all live from Link session
    - Show IP address on boot (two 2-second screens before BPM mode)
    - Remove nudge buttons and LED; encoder knob now handles BPM sync correction
    - Encoder press enters time signature menu (2–7 beats/bar, 3s timeout)
    - UDP OSC server on port 8000: /tap /bpm /signature /nudge_up /nudge_down /downbeat
    - linkQuantum is now a runtime variable driven by menu or OSC /signature
    [main.cpp]
2026-06-20 Add full menu system with NVS persistence — SIG/StEP/nudG/brit/rSEt
    - Replace single time-sig menu with 5-item menu: beat, StEP, nudG, brit, rSet
    - NAV/EDIT/CONFIRM state machine; tap button exits menu and performs tap
    - Settings (time sig, BPM step, nudge ms, brightness) persisted to NVS flash
    - Factory reset via rSet -> Sure confirmation
    - 7-seg labels use corrected lowercase glyphs (e, g, a)
    - Menu idle timeout raised to 6s
    - BPM_MAX raised to 360 in tap_tempo.h
    - Fix PIN_TAP_BUTTON/PIN_ENC_SW swap vs previous commit
    [main.cpp]
2026-06-20 Add network menu items, static IP support, and 7-seg glyph fixes
    - Menu expands to 18 items: net mode, IP/subnet/gateway octets (visible only in static mode), factory reset moved to last
    - NVS persistence for all network settings; factory reset clears them to defaults
    - ethernet_config.h: initEthernet() accepts net mode + IP config; static IP stops DHCP client and marks connected on link-up event
    - Confirming net mode change shows bOOt for 2s then reboots to apply
    - 7-seg: dHCP rendered as dhcP using lowercase h (CEFG=0x17) and c (DEG=0x0D)
    [ethernet_config.h, main.cpp]
2026-06-20 Fix spurious reboot on net mode confirm when value unchanged; add user manual
    [main.cpp]
2026-06-20 Overhaul menu system: Acc. preset, sub-menus, relabelling, sensible IP defaults
    - Replace separate StEP/nudG items with single Acc. preset (Lo/Std/Hi)
    controlling both encoder step and OSC nudge amount simultaneously
    - Collapse 12 flat IP/subnet/gateway octets into 3 parent items (IP,
    Sub., Hub.) each with a 4-octet sub-menu (Oct1–Oct4 + done to exit)
    - Add MODE_SUBMENU_NAV / MODE_SUBMENU_EDIT app modes
    - Rename display labels: beat→Beat, brit→Led, nEt→Lan., dhcP→Auto,
    StAt→Stat; add CH_B, CH_H, CH_L, CH_o glyphs
    - Default static IP to 192.168.1.200 / 255.255.255.0 / 192.168.1.1
    - Update MANUAL.md throughout to match new menu structure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
    [main.cpp]
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2026-06-20 Add version menu item and done exit item to main menu
    - MENU_VER: read-only item showing firmware version as major.minor.patch
    (e.g. 1.0.0); pressing it resets the idle timeout so the user can read it
    - MENU_DONE: exits menu on press, consistent with sub-menu done behaviour
    - Version defined via FW_MAJOR/FW_MINOR/FW_PATCH in main.cpp
    [main.cpp]
2026-06-21 Move tap button from IO4 to IO12 to free IO4 for future use
    IO12 is safe as INPUT_PULLUP after boot — its internal pull-down ensures
    correct 3.3V flash strapping before software runs.
    [main.cpp]
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2026-06-22 Fix battery SoC reading and add dampening; menu remembers position
    Correct ADC full-scale constant from 3100 to 3900 mV (ESP32
    ADC_ATTEN_DB_12 actual range). Average 16 samples per read and
    apply EMA filter (~0.8 s time constant) to eliminate display jitter.
    Menu no longer resets to item 0 on entry — resumes at last position
    after timeout.
    [main.cpp]
2026-06-22 Add OTA firmware update via Upd. menu item
    New 'UPd.' menu item downloads firmware.bin from GitHub Pages over
    HTTPS and flashes it to the inactive OTA partition, then reboots.
    Display shows percentage during download, 'donE' on success, 'Er'
    on failure. Menu returns to nav on failure without rebooting.
    Switched to two-slot OTA partition table (2x 1.5MB in 4MB flash),
    NVS kept at 0x9000 so all user settings survive the transition.
    Full Mozilla CA bundle enabled for certificate verification.
    [partitions.csv]
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2026-06-22 Add factory partition, OTA rollback, and true factory reset (v1.2.0)
    Partition table restructured to factory (1.3MB) + ota_0 (1.3MB) +
    ota_1 (1.3MB), fitting exactly in 4MB. Firmware now calls
    esp_ota_mark_app_valid_cancel_rollback() on every clean boot so a
    bad OTA rolls back automatically. Factory reset also erases otadata
    (guarded: only when a factory partition exists) so the bootloader
    returns to the originally-installed firmware. Devices upgraded via
    OTA without a factory partition degrade gracefully to settings-only
    reset. Switch CA bundle from FULL to CMN.
    [partitions.csv]
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2026-06-22 Replace button menu control: long press enters menu, short tap navigates
    Hold tap button 2 s to enter menu from normal mode. In menu, short
    tap cycles items/values forward; long press selects, confirms, or
    triggers actions. Short tap cancels the rSEt confirm screen. Encoder
    navigation left in place unchanged for now.
    [main.cpp]
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2026-06-22 Add WiFi AP provisioning, HTTP config server, AP menu item (v1.3.0)
    On first boot (no credentials stored) tapbox starts a tapbox WiFi AP
    (open, 192.168.4.1). Connect and open the browser to configure WiFi
    credentials and all device settings. On save, settings are written to
    NVS and the device reboots as a WiFi client on your network.
    WiFi shuts down after 60 s if no client connects or STA fails to
    associate. AP menu item restarts the access point at any time.
    Partition table changed to 2-slot layout (factory 0x1F0000 + ota_0
    0x1F0000), giving 1.875 MB per slot with 657 KB headroom.
    Requires reflash via programmer to update partition table.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
    [partitions.csv]
2026-06-22 v1.3.0: two-button control, WiFi with AP provisioning, dynamic Eth/WiFi switching
    Controls:
    - Replace rotary encoder with select button on IO4 (confirm/back)
    - IO36 (ADC1_CH0) for battery ADC, avoiding ADC2/WiFi conflict
    - Tap button: navigate menu and auto-increment values on hold
    - Select short press: confirm/enter; long press (1 s): back/exit
    WiFi:
    - AP mode provisioning: creates open "tapbox" AP when no credentials stored
    - Browser config page at 192.168.4.1 for SSID, password, and display settings
    - STA mode: connects as WiFi client with stored credentials
    - Auto-shutdown after 60 s if no connection established
    - AP menu item to restart access point at any time
    - Reduced TX power (8.5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
    [main.cpp]
2026-06-22 Remove AP menu item; fall back to AP automatically on STA timeout
    When WiFi STA fails to connect within 60 s, switch to AP mode instead
    of stopping WiFi entirely. This makes reconfiguration self-healing:
    unplug Ethernet, wait for STA to fail, tapbox opens the config AP.
    No menu item needed.
    [main.cpp]
2026-06-22 Improve WiFi STA fallback: immediate AP on failure, one retry on dropout
    On first connection attempt failure (never connected): fall back to AP
    immediately instead of waiting 60 seconds. Remove the 60 s timeout entirely.
    On dropout after successful connection: retry once, then fall back to AP
    if the retry also fails. Achieved by resetting s_wifi_joined before the
    retry so the next disconnect event takes the AP path.
    [main.cpp]
2026-06-22 Move OTA update to boot gesture: hold both buttons at power-on
    Remove UPd. menu item to prevent accidental mid-show updates.
    OTA now triggers by holding tap + select buttons while powering on.
    Device waits for Ethernet then runs perform_ota() showing UPd. and
    progress on the display as before.
    [main.cpp]
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2026-06-22 Fix Ethernet/WiFi switching for static IP; IP splash for all cases
    Static IP never fires IP_EVENT_ETH_GOT_IP, so eth_got_ip_cb was never
    triggered on reconnect. Add eth_connected_cb on ETHERNET_EVENT_CONNECTED
    that sets g_eth_got_ip only when ethConnected is already true (static IP
    case — ethernet_config.h sets it in the same event, registering first).
    DHCP mode is unaffected since ethConnected is still false at CONNECTED.
    [main.cpp]
2026-06-22 Replace IP splash with scrolling ticker showing connection type and IP
    show_scroll_splash(label, ip) scrolls right-to-left at 500 ms/step.
    Label prefixes: "Eth", "SSID", "AP". Dots in IP addresses are merged
    as DP onto the preceding digit. Used on all connection events:
    Ethernet boot, WiFi STA got IP, AP start, and Ethernet reconnect.
    [main.cpp]
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2026-06-22 Start HTTP config server on Ethernet connection, not just WiFi
    http_server_start() is now called whenever any connection is established:
    Ethernet at boot, Ethernet reconnect, WiFi STA got IP, and WiFi AP start.
    The settings page is accessible at the device IP on port 80 regardless
    of which interface is active. Also fix stale log message in wifi_stop().
    [main.cpp]
2026-06-22 v1.4.0: Ethernet HTTP server, config page split, AP scroll, Link/nudge cleanup
    - HTTP config server now starts on Ethernet connection (boot and runtime
    reconnect), so the settings page is reachable regardless of interface.
    - Config page split into two sections: Network (WiFi/Ethernet, reboots on
    save) and Display (brightness, time signature, nudge, applies live).
    Orange button on the network form signals the reboot. Save redirects
    back to the settings page without an intermediate confirmation page.
    - Ableton Link no longer starts in AP mode — only enabled on Ethernet or
    WiFi STA connection. AP mode shows a continuous non-blocking scroll of
    AP 192 168 4 1 on the display instead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
    [main.cpp]
2026-06-23 v1.5.0: Boot time optimisations and internal cleanup
    - Ethernet wait reduced from 10 s to adaptive: 3 s (static IP) / 5 s (DHCP)
    - IP splash scroll is now non-blocking — device responds to buttons and OSC
    during the scroll; step time reduced from 500 ms to 300 ms
    - WiFi credentials loaded in single NVS read at boot (no second open in wifi_init)
    - Sub-menu IP/subnet/gateway octets now batch-written to NVS on exit rather
    than once per octet confirmation
    - Button handlers refactored: shared BtnCtx struct + btn_poll() eliminates
    duplicate debounce/long-press logic between tap and select buttons
    - Dead variable s_wifi_start_ms removed; now_ms() double-calls fixed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
    [main.cpp]
2026-06-26 v1.6.0: Brownout protection, 4-level brightness, full WiFi power restored
    - Detect ESP_RST_BROWNOUT at boot and force display brightness to level 1 to
    reduce current draw; user can override via the Led menu
    - Brightness menu simplified from 15 steps to 4 levels (1-5-10-15 intensity map)
    - Removed WiFi TX power cap (was 8.5 dBm); CN6009 step-up removed from hardware,
    new combined board on order eliminates the minimum input voltage constraint
    - Bump FW_MINOR to 6
    [main.cpp]
2026-06-26 v1.6.2: OTA and factory reset moved from menu to button combos
    Both system functions triggered by holding both buttons in normal mode.
    OTA: hold 3 s, release; device reboots and updates on next network connection.
    Factory reset: hold 8 s, confirm with select (tap or timeout cancels).
    Boot-time both-button trigger removed; replaced by NVS ota_pend flag.
    rSEt hidden from menu; s_bh_state guards prevent spurious button actions.
    [main.cpp]
2026-06-26 v1.6.3: OTA update now requires confirmation like factory reset
    Hold both 3 s, release -> display shows UPd SurE; press select to confirm
    OTA (tap or 6 s timeout cancels). Tap cancels both confirm prompts.
    [main.cpp]
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2026-06-26 v1.6.4: Button combos require menu to be open first
    OTA (3 s) and factory reset (8 s) both-button holds now only activate
    from MODE_MENU_NAV, not from normal mode. Prevents accidental triggers
    during normal operation. README and MANUAL updated accordingly.
    [main.cpp]
2026-06-26 v1.6.5: Remove tap long-press to enter menu; fix both-button suppression in normal mode
    Tap long-press opening the menu was a leftover from single-button experiments.
    Select short-press is the only way to open the menu now.
    Also fixes both-button hold in normal mode: s_bh_state is now always set to
    BH_HELD when both buttons are pressed, suppressing individual actions (including
    the old menu long-press) in all modes. The 3 s / 8 s actions still only fire
    from MODE_MENU_NAV.
    [main.cpp]
2026-06-26 v1.6.6: Fix spurious menu open on both-button release in normal mode
    Always set long_fired on both button contexts when exiting any combo state,
    not just OTA/reset transitions. Prevents select short_rise on release from
    opening the menu after a both-button hold in normal mode.
    [main.cpp]
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2026-06-26 v1.7.1: CDJ downbeat phase sync + browser-based CDJ simulator
    - Parse beat-in-bar (Bb, byte 0x5c) from Pro DJ Link packets
    - Snap Ableton Link bar phase to CDJ downbeat on every 4->1 transition
    - Reset phase tracking when active player changes
    - tools/cdj_sim_web.py: browser GUI simulator (http://localhost:8080)
    serving self-contained HTML; Downbeat button forces Bb=1 immediately
    - Updated README and MANUAL with simulator documentation
    [main.cpp]
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2026-06-30 Add INMP441 audio beat detection (Audio mode) + 3-way sync mode
    - New Audio mode: I2S mic auto-detects BPM, tap sets the downbeat
    - Replace CDJ on/off toggle with 3-way sync mode (CDJ/Audio/Manual)
    - Pin remap: buttons to IO35/IO39 (external pull-ups), I2S on IO4/IO12/IO36
    - Remove battery ADC/monitoring (IO36 reused for mic data)
    - Beat tracking: band-pass onset detection, tap-anchored accept window,
    interval averaging, deadband, slew limit, octave-trap clamp, phase-lock
    - Display: mode bars (top=CDJ/mid=Manual/bottom=Audio) + C/A lock indicator
    - Mic tuning menu items (uind/SLEu/thr/gAte); early-boot lamp-test
    - Docs: BEAT_DETECTION.md + README/MANUAL updates
    Checkpoint before audio-fra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
    [main.cpp]
2026-06-30 v1.7.2: lock dot indicator, CDJ downbeat fix, display image, doc updates
    - Lock indicator moved to decimal point on beat-count digit (solid=locked,
    blinking=Audio searching) replacing the C/A glyph in digit 6
    - CDJ downbeat snap now triggers on any bb==1 transition (not just 4->1),
    fixing the simulator Downbeat button and out-of-sequence CDJ downbeats
    - Added g_manual_locked flag so Manual mode shows lock dot after first 4-tap
    - Added docs/display.jpg annotated display layout illustration
    - BEAT_DETECTION.md updated: 32 kHz, 4 ms blocks, alpha 0.03, sub-frame
    timing described as implemented (not planned)
    - README and MANUAL updated to match
    - Component images reorganised into component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
    [main.cpp]
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2026-07-01 v1.8.0: AP mode fully operational, AP/Addr menu items, direct-connection docs
    - AP mode (new Lan. option) now enables Ableton Link, tap, CDJ, and Audio
    sync identically to Ethernet/STA; boot skips Ethernet init entirely
    - go_live() AP guard removed; g_ap_started flag re-enables Link on the AP
    interface with the same settle cycle used by ETH/STA reconnects
    - AP boot splash changed from a looping scroll to the same one-shot splash
    used for Eth/StA, then hands off to normal BPM/phase/peers display
    - New Addr menu item (read-only): shows last IP octet as quick reference;
    press select to scroll full IP address across the display
    - README: new Direct Connection section (WiFi AP + direct Et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
    [main.cpp]
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2026-07-01 Static-IP reboot-on-exit and Addr interface label
    Reboot once on menu exit when static IP config changes:
    Switching the Lan. menu to Static previously rebooted immediately, landing
    on the default 192.168.1.200 before IP/Sub/Hub could be set, and later octet
    edits never applied (initEthernet only runs at boot). Now snapshot the network
    config on menu entry and reboot exactly once on exit (long-press, done, or
    timeout) if net mode or any IP/Sub/Hub octet actually changed.
    Show interface label on the Addr scroll:
    The Addr menu item now prefixes the scrolled IP with the active interface
    (Eth / StA / AP), matching the boot splash, instead of scrolling the bare IP.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
    [main.cpp]
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2026-07-01 v1.9.0: WiFi static IP, on-device menu trim, nudge OSC rework
    - WiFi STA now supports static IP (was Ethernet-only); Lan./IP/Sub./Hub.
    apply to whichever interface is active
    - On-device menu trimmed to Beat, Led, node, Lan., Addr, rSet, vEr, done;
    IP/Sub./Hub. octets and mic-tuning params (uind/SLEu/thr/gAte) moved to
    the web config page only
    - Web config: added Access Point network mode option and mic-tuning fields
    - Removed "nud" entirely (menu, web, NVS); OSC /nudge_up and /nudge_down
    replaced with a single /nudge <ms> (signed, defaults to 20ms)
    - Default sync mode switched from CDJ to Audio
    - Fixed: long-pressing select from edit mode now backs out to menu nav
    instead of discar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
    [main.cpp]
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2026-07-02 v1.11.0: kick-filter tuning, web page polish, updated screenshots
    - Added a 5th BPM-tuning slider: Kick filter (60-300Hz), the low-pass cutoff
    that decides what counts as "kick" energy before the other four controls
    ever see it. Recomputed live each mic block; default 150Hz matches the old
    fixed constant. Persisted as "mfreq".
    - BPM tuning chart: fixed 5-decade log scale (never rescales; a loud transient
    can't throw off the reading), faint decade gridlines, log gate slider now
    maps linearly to the red line's height.
    - Measured/Link BPM moved above the chart as large tabular-nums numbers with a
    fixed-width color-coded state badge (idle/searching/locked) — no more layout
    jitter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
    [main.cpp]
2026-07-02 v1.11.1: fix beat-lock logic — chain acceptance + tempo-aware hold
    Two lock bugs found via the tuning UI:
    1. Lock never dropped with 0 accepted beats: the lock-timeout was refreshed
    by every raw detection, so a detector spamming false onsets kept the lock
    alive forever. lastOnset now only updates on ACCEPTED beats.
    2. That fix alone made the lock flicker ("hardly locking"): acceptance
    judged the interval between CONSECUTIVE raw detections, so one spurious
    hit between two kicks split the clean kick-to-kick interval into two
    fragments that both failed the tempo test (~29 detected / 6 accepted per
    10s in the field). Detections are now judged by spacing from the last
    ACC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
    [main.cpp]
2026-07-03 WIP: grid v2 quality-weighted re-anchoring + blit-scroll tuning chart
    - A/B accept-test toggle g_micGrid (0=chain+fold production, 1=phase grid),
    selectable on the web tuning tab, not NVS-persisted
    - Grid v2: quality-weighted re-anchoring (q = 1 - |err|/w, gmax = 0.8) so
    edge-of-window hits barely move the reference; fixes v1 jitter inheritance
    - Telemetry packet extended to 13 fields (anchorBPM, devBPM, onsetAgeMs)
    - docs/tuning.js: blit-scroll oscilloscope renderer, loaded via ?js= dev
    hook; embedded page copy in main.cpp still the old renderer (fold back
    before release)
    - Ignore .vscode/ (machine-generated PlatformIO config)
    A/B verdict still open — needs a loud/long listening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
    [main.cpp]
2026-07-03 Case: switch to USB-C/TP4056 charging module, use boards.scad
    Replaces micro-USB (hw_107) cutout with USB-C via TP4056 charge board,
    updates WT32 mounting posts and bracket STL to match.
    [tapbox_case.scad, tapbox_case_WT32_bracket.stl, tapbox_case_base.stl]
2026-07-04 Replace kick-filter beat detector with FFT/BTrack DSP pipeline
    The old time-domain kick-band filter capped out around 30-50% beat
    acceptance and had no real path to improve. Ported the MIT-licensed
    absent42/esphome-audio-reactive DSP core instead: FFT -> mel filterbank
    -> SuperFlux onset detection -> BTrack (cumulative-score DP + harmonic-
    template tempo induction), re-deriving all frame-rate-dependent
    constants for tapbox's 32kHz mic (62.5Hz hop rate vs. the vendor's
    86.13Hz). An initial simpler pass (OnsetDetector/BeatTracker, no PSRAM
    needed) shipped first but drifted from a 126 BPM ground truth to a
    stable-but-wrong ~133 BPM on real hardware -- the same systematic bias
    the vendor's own c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
    [agc.h, btrack.h, main.cpp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]
2026-07-05 Follow/hold tempo redesign: BTrack owns the tempo, gates become tunable
    Testing showed BTrack's tempo estimates were consistently better than the
    guard rails protecting them (beats Rekordbox and Pulse-via-loopback in
    accuracy), so the old acceptance machinery is gone and replaced with a
    follow/hold design:
    - FOLLOW: on a confident BTrack beat, snap the tracked tempo straight to
    the octave-folded candidate — no accept window, no slew limiter, no
    standing measured-vs-Link offset (deadband only swallows <0.4 BPM jitter)
    - HOLD: anything less confident freezes the tempo; beats above the lock
    tier still feed the lock and phase-lock PLL but cannot move the tempo
    - Three tunable gates on t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
    [main.cpp]
2026-07-05 README rewording; case: microphone holder mount, battery bulkhead tweaks
    - README: rephrase intro to reflect CDJ/audio/tap tempo sources, drop stale
    web-config screenshot link
    - Case: add inmu441_microphone_holder() module + cutout/mount in case_base();
    widen battery bulkhead clearance slots; corner-rounding helper simplified
    to use donut() directly instead of the removed rounded_disk() wrapper
    [tapbox_case.scad]
2026-07-05 Case: chamfered-edge geometry rework, move SCAD/STL into case/
    Reworks case_base/lid corner and edge geometry (chamfer, separate
    top/bottom edge radii) and regenerates the STL exports; moves all
    case SCAD/STL files into a dedicated case/ directory.
    [tapbox_case.scad, tapbox_case.stl, tapbox_case_WT32_bracket.stl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]
2026-07-05 Docs: render menu-label/confirm-prompt text as glyph images; rename node->Src; firmware: Sure->Yes
    - Add tools/menu_designer.html: a segment-accurate 8-digit display
    designer (matches include/max7219.h and the CH_* glyph table),
    used to generate all the images below directly from real segment
    data instead of hand-typed approximations.
    - Rename the sync-mode menu item from "node" to "Src" (README/MANUAL),
    and replace the inconsistently-cased backtick text for every menu
    name (Beat/Led/Src/Lan./Addr/vEr/done) and OTA/factory-reset confirm
    prompt with rendered glyph images, so the docs show exactly what the
    display shows instead of an ambiguous approximation.
    - Firmware: change th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
    [main.cpp]
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2026-07-05 Firmware: web Tap button + /tap OSC consistency fix
    Adds POST /tap (calls the same do_tap() the physical button and OSC /tap
    now share) plus a round Tap button in the web config page header. Already
    flashed; this just brings the repo in sync with what's on the device.
    [main.cpp]
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
